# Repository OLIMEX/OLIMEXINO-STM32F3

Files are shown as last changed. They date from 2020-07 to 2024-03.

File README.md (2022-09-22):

# OLIMEXINO-STM32F3
Industrial grade -40+85C Arduino IDE programmable board with STM32F303RCT6TR Cortex-M4 CAN and USB

# OLIMEXINO-GD32F3
Industrial grade -40+85C Arduino IDE programmable board with GD32F303RCT6 Cortex-M4 CAN and USB

Product page: https://www.olimex.com/Products/Duino/STM32/OLIMEXINO-STM32F3/open-source-hardware

## Licensee
* Hardware is released under CERN Open Hardware Licence Version 2 -
Strongly Reciprocal
* Software is released under GPL3 Licensee
* Documentation is released under CC BY-SA 3.0

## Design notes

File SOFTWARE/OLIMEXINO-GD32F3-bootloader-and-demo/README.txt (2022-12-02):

The software in this archive applies only for OLIMEXINO-GD32F3

It is NOT suitable for OLIMEXINO-STM32F3

Folder "Bootloader" contains USB DFU bootloader and instructions

Folder "Blink-demo" contains blink and button demo binary and instructions

Folder "Sources" contains IAR EW sources for both the bootloader and blink

Folder "Arduno-Blink-32F3" contains Arduino project for blinking LEDs

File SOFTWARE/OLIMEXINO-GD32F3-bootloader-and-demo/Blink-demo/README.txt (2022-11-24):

Blink demo binary for OLIMEXINO-GD32F3

The demo sets the two LEDs alternatively blinking and you can pause the blinking by pressing
the SW1 button.

The demo was made with IAR EW for ARM. 

You can download the binary to your board via the microUSB connector and USB cable. 
You need to install the DFU USB drivers and your OLIMEXINO-GD32F3 needs to have USB bootloader 
software programmed (it can be found in the "Bootloader" folder).

The drivers can be downloded from GD32's web site:

https://gd32mcu.com/en/download/0?kw=GD32F3

Expand "Tool & Software" and download "GD32 Dfu Drivers". In the same place you can also find 
"GD32 All in One Programmer" so make sure to download and install that one too.

After installing the drivers start "GD32 All in One Programmer" (if you haven't already).

Load the binary. Click connect. Start Address at 0x80008000. Be careful if you use the wrong 
address you can overwrite the USB bootloader!!!

Connect the board to the micro USB cable, then set the board in USB DFU mode - this is done 
by resetting the board with button SW2 and quickly pressing SW1 (while the two LEDs are blinking 
very quickly). You have approximately 2 seconds between reset and pressing SW1 before the 
board would proceed with the user code exection. If you miss the window to press the button, 
simply reset again. When successfully set in USB DFU mode it should be listed as "GD32 Device 
in DFU mode" in your operating system.

Click download.

Refer to the picture "2-USB-gd32-allinoneprogrammer.png".

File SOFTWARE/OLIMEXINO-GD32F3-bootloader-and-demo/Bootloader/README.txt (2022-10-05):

USB bootloader binary for OLIMEXINO-GD32F3

You can download it to your board via USB-serial adapter attached 
to UEXT pins #2, #5, #6 and "GD32 All in One Programmer".

Alternatively you can use JTAG/SWD programmer using the 0.05" step
10-pin connector.

The drivers can be downloded from GD32's web site:

https://gd32mcu.com/en/download/0?kw=GD32F3

Expand "Tool & Software" you can find "GD32 All in One Programmer" 
make sure to download and install it.

Start Address at 0x80000000.

Refer to the "1-serial-gd32-allinoneprogrammer.png" picture.

If using the serial bootloader to download the USB bootloader,
remember to enter UART bootloader mode: press and hold button SW1,
press and release reset button SW2, release button SW1.

Instructions on how to use the newly downloaded USB DFU bootloder
can be found here:

https://github.com/OLIMEX/OLIMEXINO-STM32F3/blob/master/SOFTWARE/OLIMEXINO-GD32F3-bootloader-and-demo/Blink-demo/README.txt

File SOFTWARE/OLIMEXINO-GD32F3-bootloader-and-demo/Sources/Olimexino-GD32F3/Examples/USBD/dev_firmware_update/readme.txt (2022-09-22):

/*!
    \file    readme.txt
    \brief   description of the USB DFU(device firmware upgrade) demo.

    \version 2020-08-01, V3.0.0, firmware for GD32F30x
    \version 2022-06-10, V3.1.0, firmware for GD32F30x
*/

/*
    Copyright (c) 2022, GigaDevice Semiconductor Inc.

    Redistribution and use in source and binary forms, with or without modification, 
are permitted provided that the following conditions are met:

    1. Redistributions of source code must retain the above copyright notice, this 
       list of conditions and the following disclaimer.
    2. Redistributions in binary form must reproduce the above copyright notice, 
       this list of conditions and the following disclaimer in the documentation 
       and/or other materials provided with the distribution.
    3. Neither the name of the copyright holder nor the names of its contributors 
       may be used to endorse or promote products derived from this software without 
       specific prior written permission.

    THIS SOFTWARE IS PROVIDED BY THE COPYRIGHT HOLDERS AND CONTRIBUTORS "AS IS" 
AND ANY EXPRESS OR IMPLIED WARRANTIES, INCLUDING, BUT NOT LIMITED TO, THE IMPLIED 
WARRANTIES OF MERCHANTABILITY AND FITNESS FOR A PARTICULAR PURPOSE ARE DISCLAIMED. 
IN NO EVENT SHALL THE COPYRIGHT HOLDER OR CONTRIBUTORS BE LIABLE FOR ANY DIRECT, 
INDIRECT, INCIDENTAL, SPECIAL, EXEMPLARY, OR CONSEQUENTIAL DAMAGES (INCLUDING, BUT 
NOT LIMITED TO, PROCUREMENT OF SUBSTITUTE GOODS OR SERVICES; LOSS OF USE, DATA, OR 
PROFITS; OR BUSINESS INTERRUPTION) HOWEVER CAUSED AND ON ANY THEORY OF LIABILITY, 
WHETHER IN CONTRACT, STRICT LIABILITY, OR TORT (INCLUDING NEGLIGENCE OR OTHERWISE) 
ARISING IN ANY WAY OUT OF THE USE OF THIS SOFTWARE, EVEN IF ADVISED OF THE POSSIBILITY 
OF SUCH DAMAGE.
*/

  This demo is based on the GD32F303E-EVAL board,it presents the implementation 
of a device firmware upgrade (DFU) capability in the GD32 USB device.

  It follows the DFU class specification defined by the USB Implementers Forum for 
reprogramming an application through USB-FS-Device.

  The DFU principle is particularly well suited to USB-FS-Device applications that 
need to be reprogrammed in the field.

  The supported memorys of this example are the internal flash memory, the external 
nand flash memory and the external nor flash memory.

  To test the demo, the internal flash is used as an example:

  Step 1: User need a configuration hex image or bin image. The hex image and the bin image 
should set application address at APP_LOADED_ADDR in the internal flash memory. User can refer to
"../Test_Images" folder and use the hex images and bin images in it.

  Step 2: User need install the corresponding GD DFU Driver with your PC operation system. 

  Step 3: Once the configuration *.hex image is generated, it can be downloaded into the 
internal flash memory or the external falsh memory using the GD tool "GD32 MCU DFUEx Tool
" available for download from http://www.gd32mcu.com/cn/download.

  The GD tool "GD32AllInOneProgrammer" can operate the option Byte in the internal flash.

  Step 4: After each device reset, hold down the TAMPER key on the GD32207i-EVAL board into app 
routine in the internal flash.

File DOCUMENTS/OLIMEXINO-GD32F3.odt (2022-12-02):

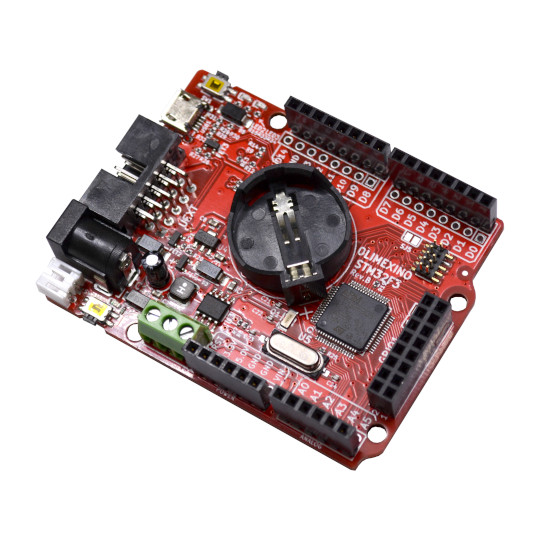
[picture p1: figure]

OLIMEXINO-GD32F3

User Manual

Document revision 1.0 December 2022

www.olimex.com

# What is OLIMEXINO-GD32F3

It is a version of OLIMEXINO-STM32F3 but with GigaDevice’s GD32F3 chip. The STM32F3 and GD32F3 chips are very similar and the variant was designed due to unavailability of STM32 chips.

## Differences between OLIMEXINO-STM32F3 and OLIMEXINO-GD32F3

The main chip is different which leads to a few major differences between the two boards. The major differences affecting the user are:

1) GD32F303 chip has no built-in USB bootloader, only serial one (USART0 or USART1 can be used to re-program the board without programmer). In order to program the board you might need either USB-serial adapter cable SWD programmer (with proper cabling to fit the 10pin, 0.05” step on-board connector). You can find

2) Memory maps are different. If you compare the memory organization and maps in the datasheets of both chips you would notice the memory organization is different. This effectively makes almost any binary made for the STM32F3 version incompatible with the GD32F3 version. Also renders some of the tools unusable. For example, for Arduino you would have to use special core for GD32 chips, instead of the official STM32 duino project.

3) The built-in serial uses the I2C pins at the UEXT (e.g. I2C and UART are swapped in the GD32F3 board – the UEXT pins 3 and 4 are I2C and pins 5 and 6 are UART).

OLIMEXINO-GD32F3 is an industrial grade -40+85C operating temperature, Open Source Hardware board with GD32F303RCT6 main chip. The chip has 256 KB of flash memory and 48 KB of RAM. The board works with powered off a Li-Po battery without an external supply, and switching between USB to external to Li-Po battery power supply is seamless and automatic. If USB is connected the board gets powered by the USB, if external power is applied to the power jack – it has priority over the USB and battery and the board will be powered by the external power supply, if both external power supply and USB power supply are missing but a battery is connected the board would automatically get powered by the LiPo battery. In GD32F3 series of microcontrollers the CAN and the USB can work at the same time.

OLIMEXINO-GD32F3 has following features:

- GD32F303RCT6 256KB flash, 40KB RAM
- Industrial grade (-40+85)°C operating temperature
- Micro USB connector for powering and programming
- Power jack (5.5mm x 2mm) for external power supply (4.2-40)V DC
- Li-Po battery charger and connector
- Micro SD card
- RTC 32.768kHz with CR2032 battery connector
- Bootloader button
- Reset Button
- CAN driver and connector
- UEXT connector
- Arduino connectors
- Extra 16 pin GPIO connector
- 10-pin JTAG connector for programming and debugging

Product page:

https://www.olimex.com/Products/Duino/STM32/OLIMEXINO-GD32F3/open-source-hardware

# Hardware schematic, revision C1

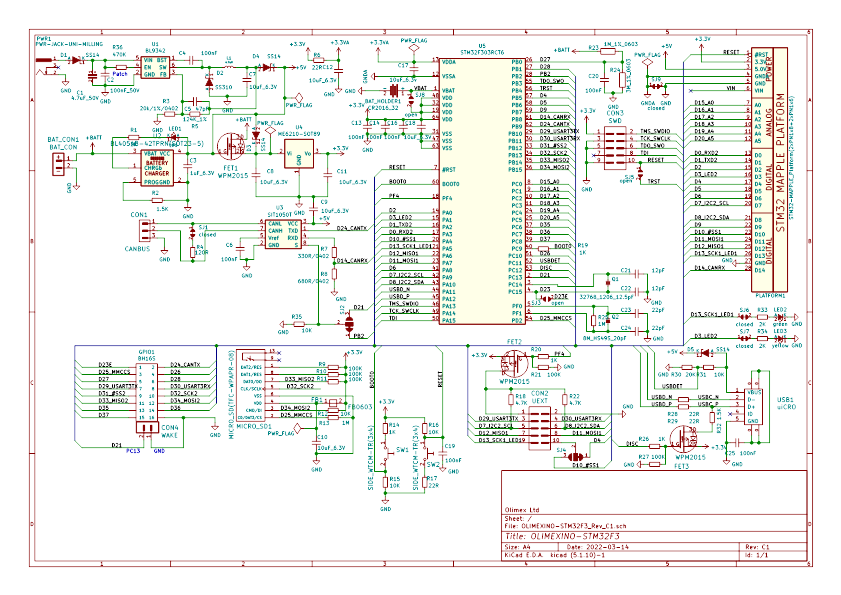
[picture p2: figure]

# Programming considerations

By default there are two ways to program the OLIMEXINO-GD32F3 – either via USB-serial cable attached to the UART pins at the UEXT; or via external programmer attached to the 10-pin SWD connector.

Alternatively, you can program the board with DFU USB bootloader, it will be possible to program it via the micro USB port too (but there is no DFU USB bootloader programmed by default).

No matter the method chosen you can use a number of software tools tool provided by GigaDevices or the Arduino community.

# Using stand-alone programmer software

The compatible software tool can be downloaded from GigaDevice’s web-site. It is called “GD32 All-In-One Programmer”. It allows to program the board via USB-serial cable, using USB DFU bootloader, or a special programmer tool “GD USB adapter”. We would cover the first two ways.

But first go to:

https://gd32mcu.com/en/download/0?kw=GD32F3

Expand the list of “Tools & Software” and download “GD32 All-In-One Programmer” from the button.

After the download is completed, extra the archive.

Inside you will find “GD32AllInOneProgrammer.exe” – run it to start the application.

## Programming via serial bootloader

You can program the board via its internal bootloader via external USB-serial adapter (with 3.3V levels). I use Olimex BB-CH340T and three wires attached to UEXT pins #2(GND), #5(TX), #6(RX). I power the board from the power jack (but you can power it from a micro USB cable too).

Once the hardware connections are established, remember to set the OLIMEXINO-GD32F3 board in bootloader mode. This is done by:

- press and hold button SW1

- press and release button SW2

- release button SW1

In “GD32 All In One Programmer” software set:

- “Interface” to “COM”;

- “BootLoader” to “UART”;

- “Port Name” to the COM port assigned to the USB-serial cable

- “Part Number” to GD32F303RCT.

- “Start Address” at “0x8000000”

- Mark “Full Chip erase”

There is a reference picture on the next page that shows how the settings look here. COM10 is where my USB-serial adapter BB-CH340T is listed by Windows.

Once done click the button “Connect”. If it doesn’t connect then double-check all previous steps, you probably swapped RX and TX wires or didn’t enter bootloader mode with the buttons.

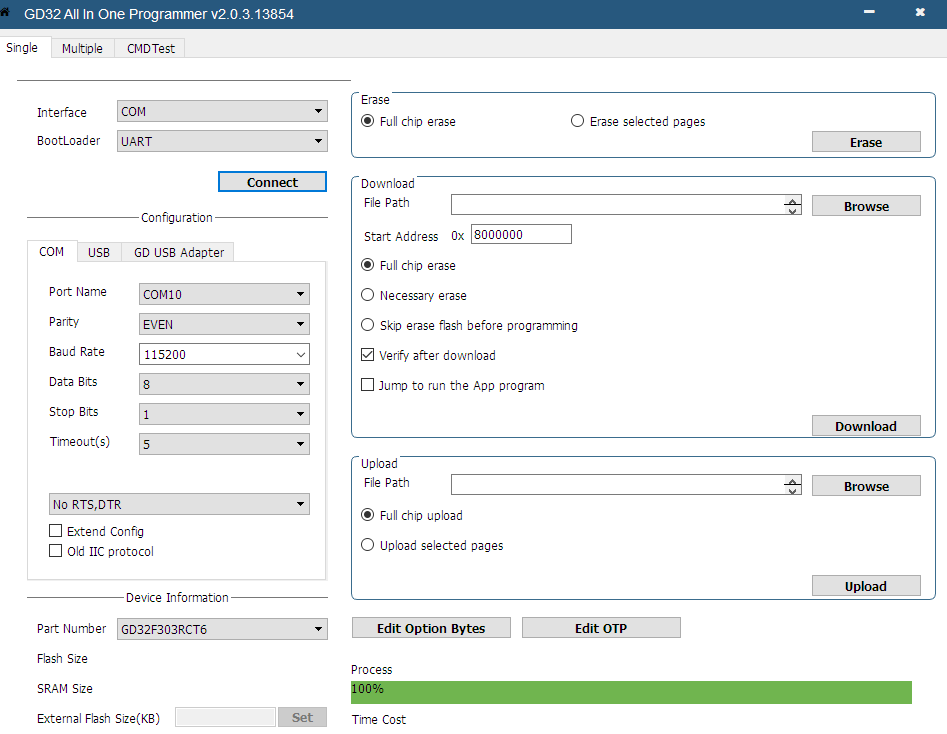
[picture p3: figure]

After the connection is successful you can download a binary from the “Download” section and navigating with “Browse” button.

## Programming via USB

OLIMEXINO-GD32F3 boards come without USB bootloader. If you wish to program the board via USB you need to first download USB bootloader via serial bootloader or via JTAG. You can find such here:

https://github.com/OLIMEX/OLIMEXINO-STM32F3/tree/master/SOFTWARE/OLIMEXINO-GD32F3-bootloader-and-demo/Bootloader

Programming via the USB requires to first install the USB drivers. The drivers can be downloaded from GD32's web site: https://gd32mcu.com/en/download/0?kw=GD32F3

Expand "Tool & Software" you can find "GD32 All in One Programmer" make sure to download and install it.

After installing the drivers start "GD32 All in One Programmer" (if you haven't already).

Load the binary. Click connect. Start Address at 0x80008000. Be careful if you use the wrong address you can overwrite the USB bootloader!!!

Connect the board to the micro USB cable, then set the board in USB DFU mode – this is done by resetting the board with button SW2 and quickly pressing SW1 (while the two LEDs are blinking very quickly). You have approximately 2 seconds between reset and pressing SW1 before the board would proceed with the user code execution. If you miss the window to press the button, simply reset again. When successfully set in USB DFU mode it should be listed as "GD32 Device in DFU mode" in your operating system.

Click download.

Refer to the picture on the next page on how GD32 All in One Programmer window looks like when programming via the USB.

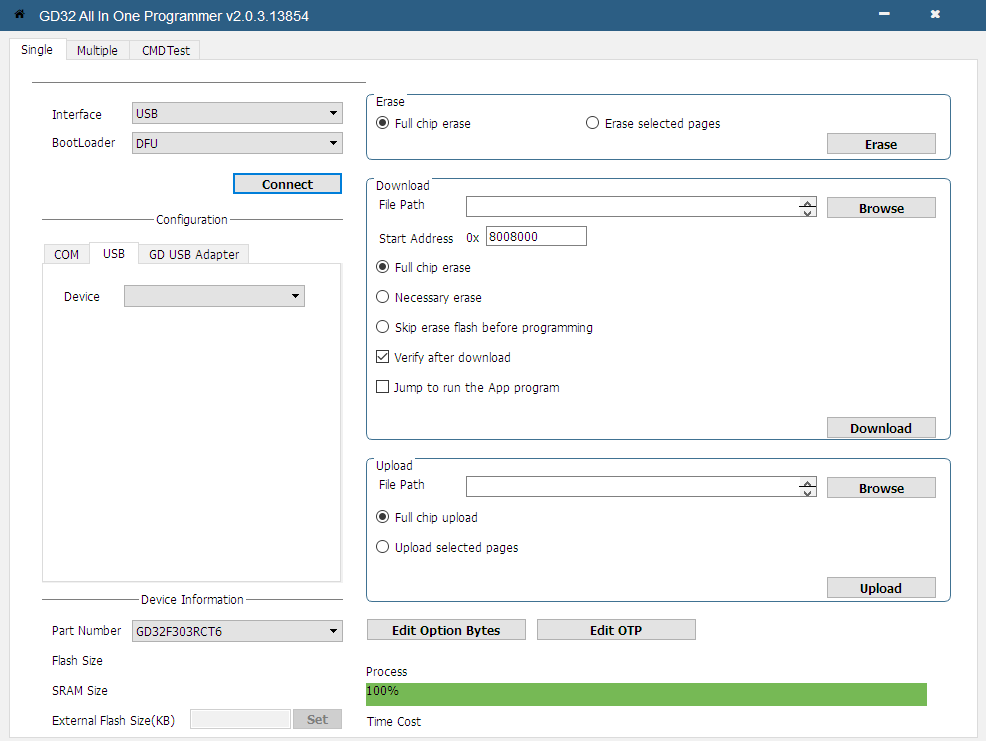
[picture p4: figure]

# Using Arduino IDE

Notice that OLIMEXINO-GD32 does not work with STM32duino package but there is a community effort project called “ArduinoCore-GD32” that can be found here:

https://github.com/CommunityGD32Cores/ArduinoCore-GD32

1. How to add “ArduinoCore-GD32” to Arduino IDE? In Arduino IDE navigate to Files→ Preferences and in “Additional Boards Manager URLs” field add the following link:

https://raw.githubusercontent.com/CommunityGD32Cores/GD32Core-New/main/package_gd32_index.json

It should looks similar to this:

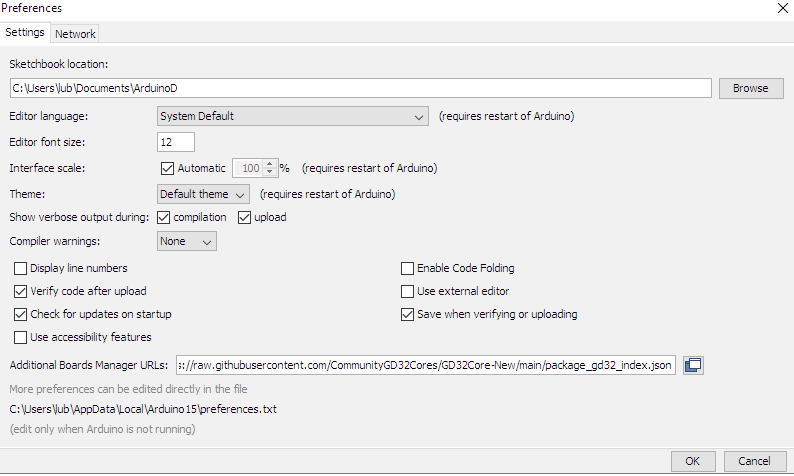
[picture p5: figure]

2. Then navigate to Tools→ Boards → Board Manager

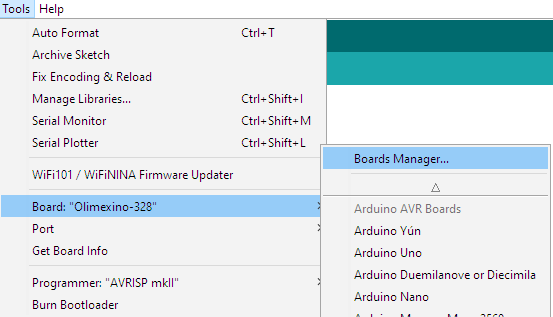
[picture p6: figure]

3. Type “gd32” to filter out the available packages then install the latest one made by “Some random folks”. Wait until installations completes. It should look similar to this:

4. Restart Arduino IDE.

5. Now select the board. Under “Board” select “GD32F30x Generic series”. It looks like this:

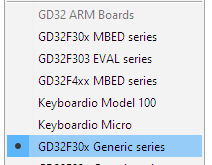
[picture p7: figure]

Now you have several paths ahead depending on how you plan to program the board. You can program it via serial bootloader, via USB DFU (not available by default), via external programmer tool with SWD interface (requires GDlink, ST-link, or J-Link programmer tool). All options are visible here:

5.1 (option serial bootloader) Under upload method remember to select “Serial”, which is serial method that requires Serial-USB adapter attached to the UEXT pins #2(GND), #5(TX), #6(RX). Power the board from the power jack (but you can power it from a micro USB cable too).

Once the hardware connections are established, remember to set the OLIMEXINO-GD32F3 board in serial bootloader mode. This is done by:

- press and hold button SW1

- press and release button SW2 (SW2 is reset button)

- release button SW1

You need to enter bootloader mode every time before clicking the Arduino IDE button “Upload”, else the upload would fail.

5.2 (option USB DFU) This only works if you have downloaded USB DFU to the board. Under upload method remember to select “dfu-util (DFU – STMDuino bootloader), which is the micro USB method.

How to download USB DFU to the board? Refer to chapter “Programming via USB” above in this document, it explains how to download the USB DFU. Now connect the board to the micro USB cable, then set the board in USB DFU mode – this is done by resetting the board with button SW2 and quickly pressing SW1 (while the two LEDs are blinking very quickly). You have approximately 2 seconds between reset and pressing SW1 before the board would proceed with the user code execution. If you miss the window to press the button, simply reset again. When successfully set in USB DFU mode it should be listed as "GD32 Device in DFU mode" in your operating system.

5.3 (option JTAG) Connect one of the three supported JTAG tools to the on-board SWD connector. It is a standard 0.05 inch step 10-pin connector. If your tool doesn’t fit and you don’t have an adapter, then consider this adapter ARM-JTAG-20-10:

https://www.olimex.com/Products/ARM/JTAG/ARM-JTAG-20-10/

Then select Tools → Upload Method → GDLink(SWD) or STLink(SWD) or Jlink(SWD), depending on the tool you have.

6. Once the chosen method for downloading code is set and selected, we have to download some code. Load a blinking LED example corresponding to the board’s hardware. Try this blinking LED code:

void setup() {

// initialize PA5(LED1) and PA1(LED2) as outputs.

pinMode(PA5, OUTPUT);

pinMode(PA1, OUTPUT);

}

// the loop function runs over and over again forever

void loop() {

digitalWrite(PA5, HIGH); // turn LED1 on (HIGH is the voltage level)

digitalWrite(PA1, LOW); // turn LED2 off by making the voltage LOW

delay(1000); // wait for a second

digitalWrite(PA5, LOW); // turn LED1 off by making the voltage LOW

digitalWrite(PA1, HIGH); // turn LED2 on (HIGH is the voltage level)

delay(1000); // wait for a second

}

Click the upload button, and wait until success. There are more example from File → Examples. They can be found under “Examples for GD32F30x Generic series”. Notice that some macros might not correspond to OLIMEXINO-GD32F3 and you might need to declare pins directly or edit variant.h in the package. It is usually located in:

C:\Users\[yourusername]\AppData\Local\Arduino15\packages\GD32Community\hardware\gd32\0.0.1\variants\GD32F303CC_GENERIC

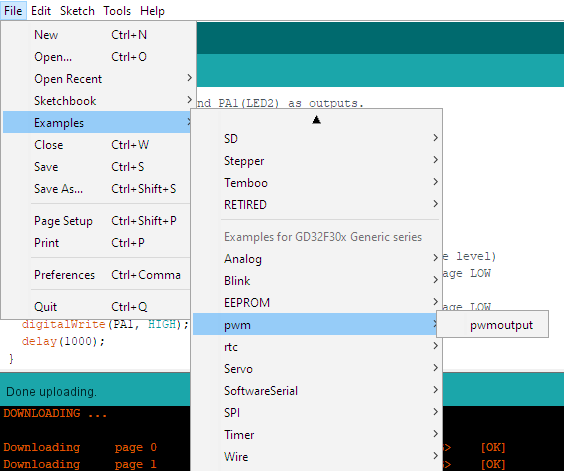
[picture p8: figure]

# Programming via JTAG

Allows for general-purpose programming of the board. This way you can use ARM development environments like IAR EW for ARM (that we have used successfully). The JTAG also can be used with certain packages in Arduino IDE and PlatformIO that have support for both GD32 chips and JTAG. Notice that “ArduinoCore-GD32” package for Arduino has support only for three JTAGs -

Notice that the OLIMEXINO-GD32F3 board has only SWD (Serial Wire Debug) interface exposed on the connector (it is not a full JTAG). Make sure your tool has SWD support. The on-board SWD connector is a standard 0.05 inch step 10-pin connector. If your tool doesn’t fit and you don’t have an adapter, then consider this adapter ARM-JTAG-20-10:

https://www.olimex.com/Products/ARM/JTAG/ARM-JTAG-20-10/

# Software examples and libraries

Notice that demos for OLIMEXINO-GD32F3 and OLIMEXINO-STM32F3 are incompatible due to memory map differences.

There is a USB DFU firmware made with IAR EW.

There is a blink demo made with IAR EW.

There is a blink demo made with Arudino IDE.

All can be found here: https://github.com/OLIMEX/OLIMEXINO-STM32F3/tree/master/SOFTWARE/OLIMEXINO-GD32F3-bootloader-and-demo

# Revision history

Revision 1.0 December 2022

- Initial release

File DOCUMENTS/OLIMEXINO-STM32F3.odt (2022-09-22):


OLIMEXINO-STM32F3

User Manual

Document revision 2.0 September 2022

www.olimex.com

# What is OLIMEXINO-STM32F3

OLIMEXINO-STM32F3 is an industrial grade -40+85C operating temperature, Open Source Hardware board with STM32F303RCT6 main chip. The chip has 256 KB of flash memory and 48 KB of RAM. The board works with powered off a Li-Po battery without an external supply, and switching between USB to external to Li-Po battery power supply is seamless and automatic. If USB is connected the board gets powered by the USB, if external power is applied to the power jack – it has priority over the USB and battery and the board will be powered by the external power supply, if both external power supply and USB power supply are missing but a battery is connected the board would automatically get powered by the LiPo battery.

In STM32F3 series of microcontrollers the CAN and the USB can work at the same time.

Notice that this guide is not suitable for OLIMEXINO-GD32F3!

OLIMEXINO-STM32F3 has following features:

- STM32F303RCT6 256KB flash, 40KB RAM
- Industrial grade (-40+85)°C operating temperature
- Micro USB connector for powering and programming
- Power jack (5.5mm x 2mm) for external power supply (4.2-40)V DC
- Li-Po battery charger and connector
- Micro SD card
- RTC 32.768kHz with CR2032 battery connector
- Bootloader button
- Reset Button
- CAN driver and connector
- UEXT connector
- Arduino connectors
- Extra 16 pin GPIO connector
- 10-pin JTAG connector for programming and debugging

Product page:

https://www.olimex.com/Products/Duino/STM32/OLIMEXINO-STM32F3/open-source-hardware

# Hardware schematic, revision C1


# Programming considerations

OLIMEXINO-STM32F3 can be programmed via a number of ways. It can be programmed via JTAG or SWD tool using its 10-pin JTAG connector; it can be programmed via the built-in USB or serial bootloader. A lot of software tools can be used. For simple programming and re-programming tasks maybe consider “STM32CubeProgrammer” stand-alone programmer software. For development work again a lot of software tools can be used depending on the goals and proficiency of the user. We would provide information about how you can program the board with Arduino IDE:

# Arduino IDE installation

1. In Arduino IDE navigate to Files→ Preferences and in “Additional Boards Manager URLs” field add the following link:

https://github.com/stm32duino/BoardManagerFiles/raw/main/package_stmicroelectronics_index.json

as shown below:

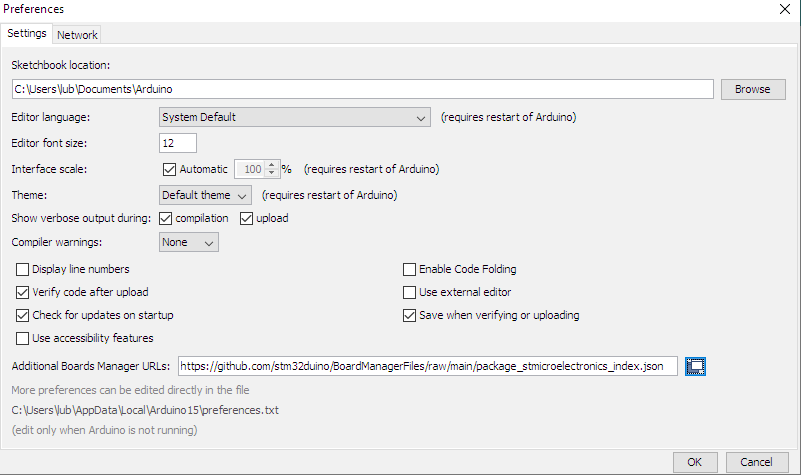
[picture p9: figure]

2. Then navigate to Tools→ Boards → Board Manager


3. Type “stm32” to filter out the available packages then install the latest one made by STMicroelectronics. Wait until installations completes. It should look similar to this:

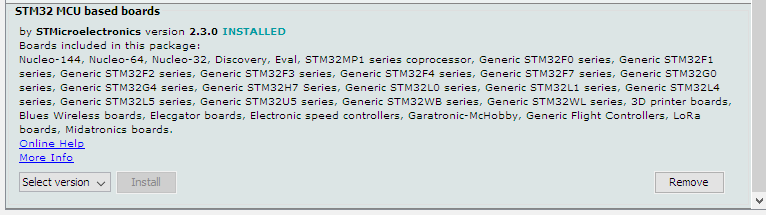
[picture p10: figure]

4. We want to upload the demo via USB DFU. And if you wish to upload via SWD, Serial, or DFU you need to install STM32 Cube Programmer (https://www.st.com/en/development-tools/stm32cubeprog.html) – make sure to download and install it.

5. Restart Arduino IDE.

6. Now select the board. Under “Board” select “Generic STM32F3 series” and under “Board part number:” go for “OLIMEXINO-STM32F3”. Under upload method remember to select DFU, which is the microUSB method (alternatively you can also serial method but that requires Serial-USB adapter attached to the GND, RX, TX pins at the UEXT connector). Follow the image below:

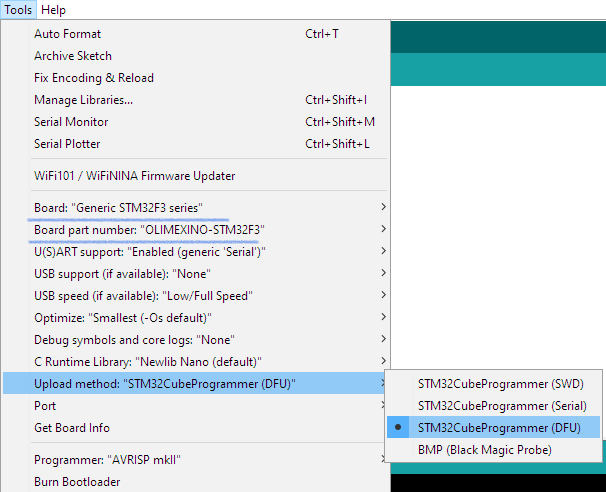
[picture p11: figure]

7. Put the board in USB DFU mode – this is done by button manipulation – press and hold down button SW1 then press and release button SW2, then release button SW1. The board should now be recognized as “STM32 bootloader”.

8. Load one of the examples from File → Examples. Maybe Examples → 01.Basics → Blink. Click the upload button and wait until success.

If you encounter issues with the installation make sure to also check the official installation instructions:

https://github.com/stm32duino/wiki/wiki/Getting-Started

# Software examples and libraries

You can find our work here:

https://github.com/OLIMEX/OLIMEXINO-STM32F3/tree/master/SOFTWARE

In GitHub software folder there are examples on how to use the GPIOs (LEDs and button), I2C, SPI (we provide new library for this as otherwise you couldn’t use the micro SD card as original Arduino library support just one SPI), CAN, UART, SD-card, LCD3310.

There is also an example with MOD-LCD2.8RTP.

# Document revision history

Revision 2.0 September 2022

- Updated installation instructions

- Updated schematic to latest one

- Minor spelling and design improvements

Revision 1.0 July 2020

- Initial release of the document

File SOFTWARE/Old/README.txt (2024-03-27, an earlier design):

These examples worked with STM32duino package 1.9.0 patched with the files inside "Package files" directory.
Read the "HowTo.txt" for further instruction on how to do it.

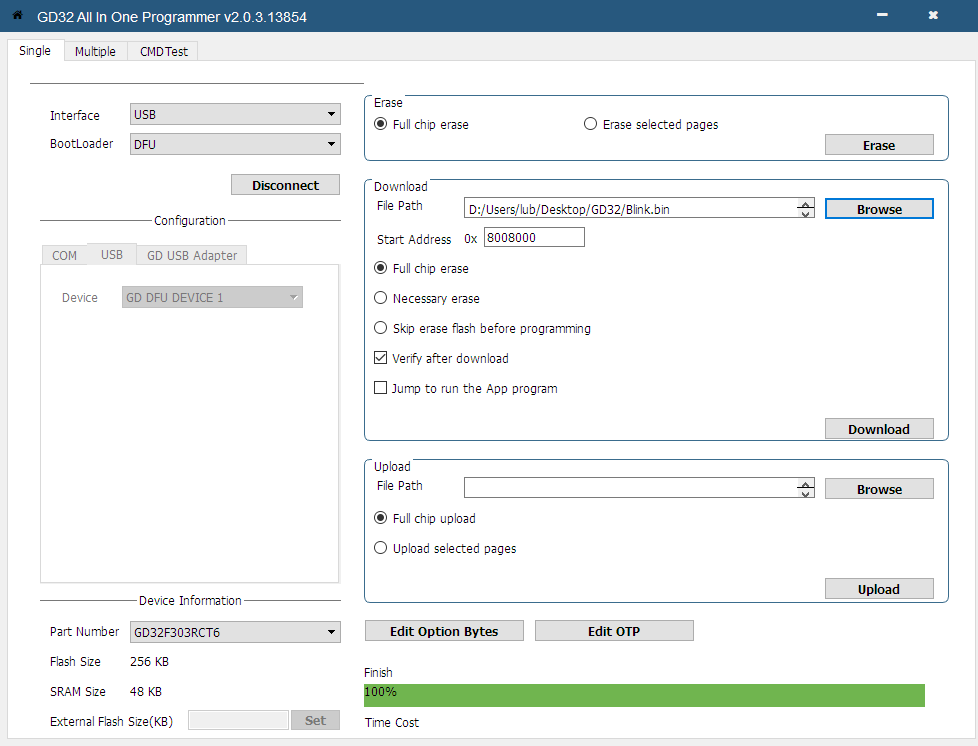
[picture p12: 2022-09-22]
SOFTWARE/OLIMEXINO-GD32F3-bootloader-and-demo/Blink-demo/2-USB-gd32-allinoneprogrammer.png

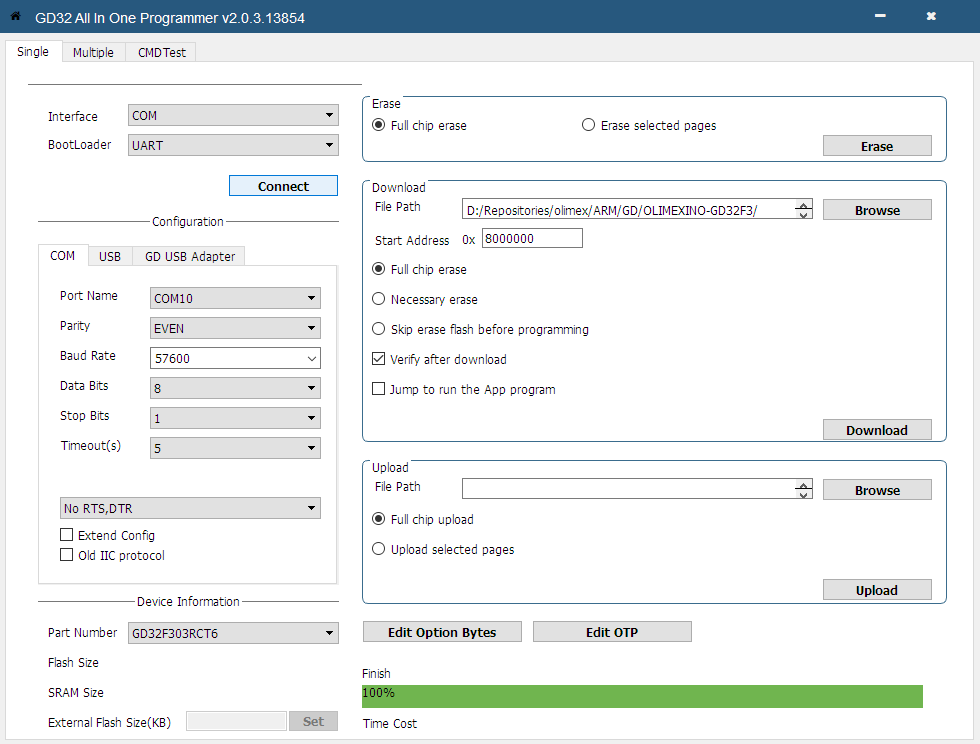
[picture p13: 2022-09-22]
SOFTWARE/OLIMEXINO-GD32F3-bootloader-and-demo/Bootloader/1-serial-gd32-allinoneprogrammer.png

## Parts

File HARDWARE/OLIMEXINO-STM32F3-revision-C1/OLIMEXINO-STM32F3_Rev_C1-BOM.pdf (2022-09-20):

# OLIMEXINO-STM32F3_Rev_C1-BOM 03/14/2022

Designation | Qua ntity | Designator | Package
SMD ДИОД 1N5819 (SS14) SMA | 4 | D5,D4,D3,D1 | SMA-KA
SMD RES 0402 124 K OHM 1% | 1 | R5 | R_0402_5MIL_DWS
SMD CAP 0603 1 UF 10V X5R | 1 | C3 | C_0603_5MIL_DWS
SMD RES 0402 20 K 1% | 1 | R3 | R_0402_5MIL_DWS
FB0603 | 1 | FB1 | L_0603_5MIL_DWS
MALE-PAV16X-2x05-LOW | 1 | CON3 | SWD /маха се 7ми крак/
n.i. | 1 | CON4 | HN1x2
SMD ИНДУКТИВНОСТ CD43 4.7 UH (NRS4018T4R7MDGJ) | 1 | L1 | CD43
SMD ИС BL4054B-42TPRN | 1 | U2 | SOT-23-5
SMD ИС BL9342 | 1 | U1 | SOT23-6
SMD ИС ME6210A33PG | 1 | U4 | SOT89
SMD ИС SIT1050T | 1 | U3 | SO-8
SMD КЛЮЧ БУТОН TSW34-W16PR-220-LF / SIDE | 2 | SW2,SW1 | TSW34-W16PR-220
SMD КОНД 0402 100 NF 10% 10VDC | 8 | C25,C20,C19,C16,C14,C13,C6,C 4 | C_0402_5MIL_DWS
SMD КОНД 0402 12 PF NP0 5% | 2 | C22,C21 | C_0402_5MIL_DWS
SMD КОНД 0402 22 PF NP0 5% | 2 | C24,C23 | C_0402_5MIL_DWS
SMD КОНД 0402 47 PF C0G 50VDC 5% | 1 | C5 | C_0402_5MIL_DWS
SMD КОНД 0603 10 UF 6.3V | 8 | C18,C17,C12,C11,C10,C9,C8,C7 | C_0603_5MIL_DWS
SMD КОНД 0805 100 NF X7R 50VDC 10% | 1 | C2 | C_0805_5MIL_DWS
SMD RES 0402 330 OHM 5% | 1 | R7 | R_0402_5MIL_DWS
SMD RES 0402 680 OHM 5% | 1 | R8 | R_0402_5MIL_DWS
SMD РЕЗ 0402 1 K 5% | 4 | R26,R20,R19,R14 | R_0402_5MIL_DWS
SMD РЕЗ 0402 1 M 5% | 2 | R25,R13 | R_0402_5MIL_DWS
SMD РЕЗ 0402 1.5 K 5% | 1 | R32 | R_0402_5MIL_DWS
SMD РЕЗ 0402 1.5 K 5% | 1 | R2 | R_0402_5MIL_DWS
SMD РЕЗ 0402 10 K 5% | 5 | R35,R31,R16,R15,R12 | R_0402_5MIL_DWS
SMD РЕЗ 0402 100 K 5% | 5 | R27,R21,R11,R10,R9 | R_0402_5MIL_DWS
SMD РЕЗ 0402 120 OHM 5% | 1 | R4 | R_0402_5MIL_DWS
SMD РЕЗ 0402 2 K 5% | 3 | R34,R33,R1 | R_0402_5MIL_DWS
SMD РЕЗ 0402 20 K 5% | 1 | R30 | R_0402_5MIL_DWS
SMD РЕЗ 0402 22 OHM 5% | 4 | R29,R28,R17,R6 | R_0402_5MIL_DWS
SMD РЕЗ 0402 4.7 K 5% | 2 | R22,R18 | R_0402_5MIL_DWS
SMD РЕЗ 0603 1 M 1% | 1 | R23 | R_0603_5MIL_DWS
SMD РЕЗ 0603 3 M 1% | 1 | R24 | R_0603_5MIL_DWS
SMD РЕЗ. КВАРЦ 32.768 kHz SMD1206 12.5pf | 1 | Q1 | L_1206_5MIL_DWS
SMD РЕЗОНАТОР КВАРЦ HU49S 8 MHZ 20PF 20PPM | 1 | Q2 | Q_49U3HMS
SMD СВЕТОДИОД 0603 ЖЪЛТ 150 mCd | 1 | LED3 | LED_0603_KA
SMD СВЕТОДИОД 0603 ЗЕЛЕН 300 mCd | 1 | LED2 | LED_0603_KA

# OLIMEXINO-STM32F3_Rev_C1-BOM 03/14/2022

SMD СВЕТОДИОД 0603 ЧЕРВЕН 300 mCd | 1 | LED1 | LED_0603_KA
SMD СЪЕДИНИТЕЛ MISB-SWMM-5B-LF | 1 | USB1 | USB-MICRO_MISB-SWMM-5B_LF
SMD СЪЕДИНИТЕЛ TFC-WPAPR-08 (микро SD-карта) | 1 | MICRO_SD1 | MICRO_SD(TFC-WXCP11-08-LF)
SMD ТРАНЗИСТОР WPM2015-3/TR | 3 | FET3,FET2,FET1 | SOT23
STM32F303RCT6 | 1 | U5 | LQFP64_Pitch-0.5mm_12.00x12.00x1.6 0mm
КЛЕМА TB3-3.5ММ (HD-351 3P) | 1 | CON1 | TB3-3.5mm
КОНДЕНЗАТОР 4.7 uF 50 V | 1 | C1 | CPOL-RM2mm_5x9mm_PTH
СЪЕДИНИТЕЛ BH-CR2032P 3V | 1 | BAT_HOLDER1 | CR2032-PTH-PLASTIC
СЪЕДИНИТЕЛ BH10R (B-R-10-LF) 2x5 ЪГЪЛ | 1 | CON2 | UEXT_BH10R LIPO_BAT-CON2D-
СЪЕДИНИТЕЛ DW02R | 1 | BAT_CON1 | W02R
СЪЕДИНИТЕЛ F-D-2X08-LF | 1 | GPIO1 | BH16S
СЪЕДИНИТЕЛ FE-D13A-1X06-LF(H=11.04mm) | 2 | PLATFORM1 | ARDUINO-STM32-PLATFORM
СЪЕДИНИТЕЛ FE-D13A-1X08-LF(H=11.04mm) | 2 | PLATFORM1
СЪЕДИНИТЕЛ YDJ-1134 PWRJ-2mm (DCJ-R-20-LF) | 1 | PWR1 | PWR_JACK_UNI_MILLI NG
SMD ДИОД SS310 SMA | 1 | D2 | SMA-KA
SMD РЕЗ 0402 470 K 5% | 1 | Rpatch | R_0402_5MIL_DWS

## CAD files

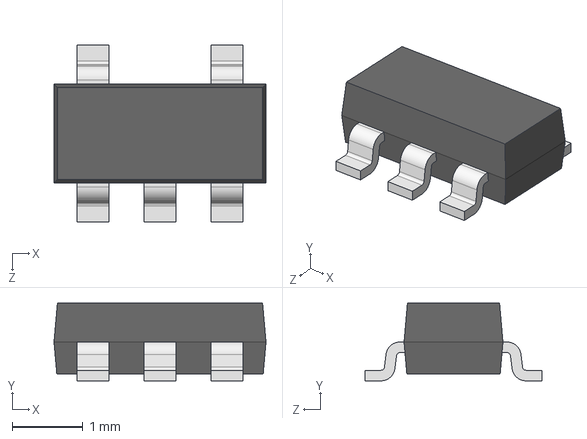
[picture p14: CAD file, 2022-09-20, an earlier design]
HARDWARE/OLIMEXINO-STM32F3-revision-B/3d/SOT-23-5.step
3.00 x 1.10 x 2.50 mm

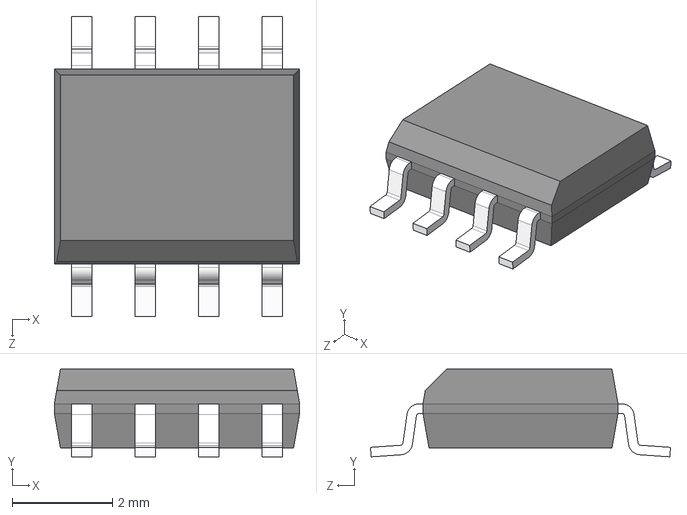
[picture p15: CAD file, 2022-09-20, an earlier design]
HARDWARE/OLIMEXINO-STM32F3-revision-B/3d/SO-8_150mil---SN65HVDA1050AQDRQ1.STEP
4.90 x 1.75 x 5.99 mm

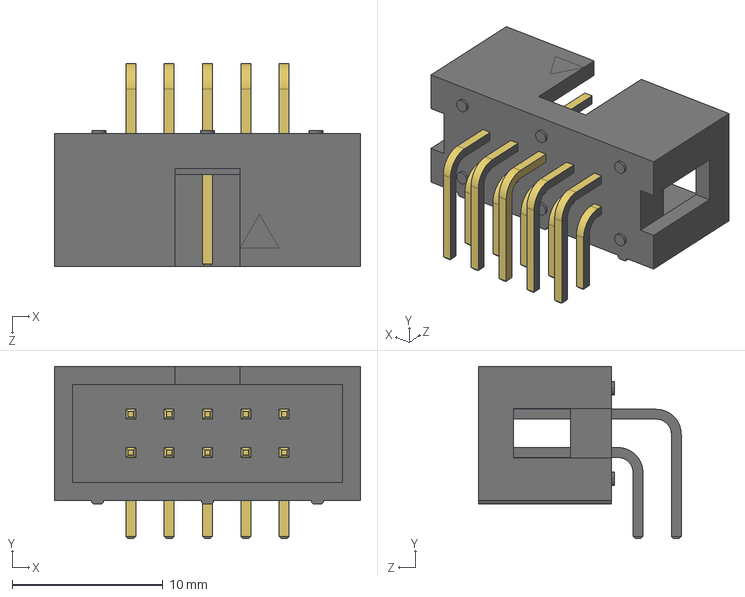
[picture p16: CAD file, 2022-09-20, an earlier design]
HARDWARE/OLIMEXINO-STM32F3-revision-B/3d/Header_right_angle_10way(2x5).step
20.3 x 11.4 x 13.4 mm

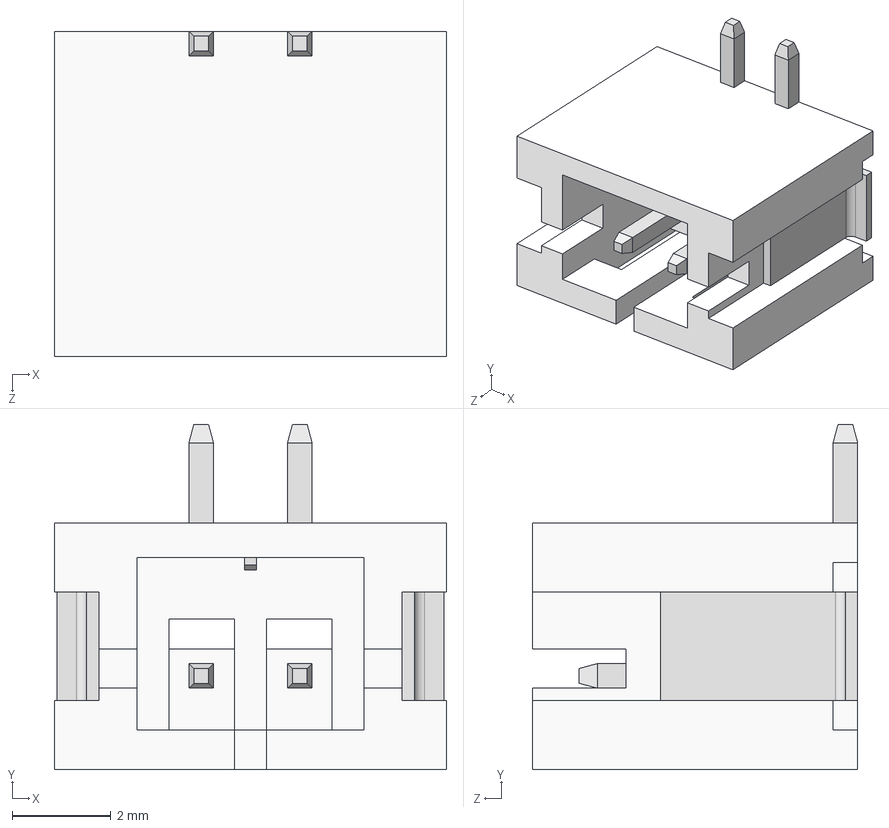
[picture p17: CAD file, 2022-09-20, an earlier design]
HARDWARE/OLIMEXINO-STM32F3-revision-B/3d/JST_B2B-PH-SM4-TB(DW02R).step
7.95 x 7.00 x 6.60 mm

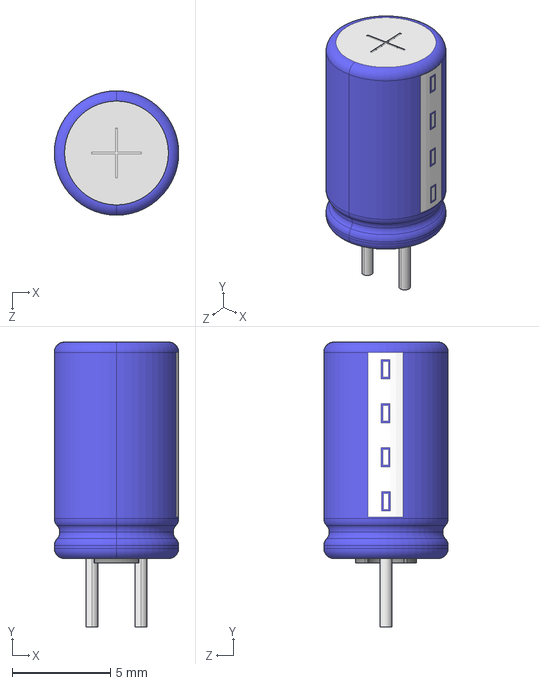
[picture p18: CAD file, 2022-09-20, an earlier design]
HARDWARE/OLIMEXINO-STM32F3-revision-B/3d/Cap_PTH_6_3x11x2_5mm.step
6.35 x 14.5 x 6.35 mm

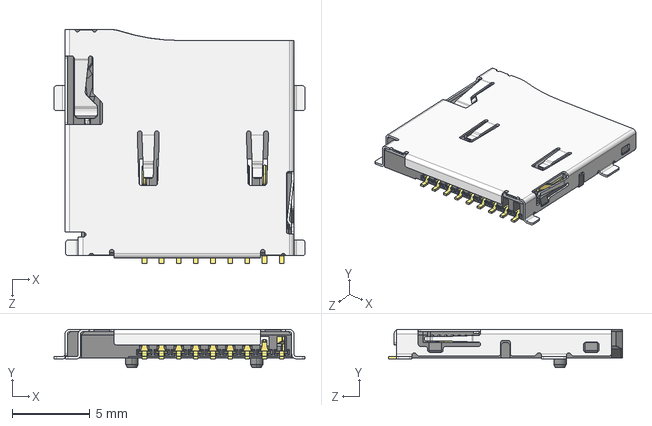
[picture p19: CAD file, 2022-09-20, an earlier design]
HARDWARE/OLIMEXINO-STM32F3-revision-B/3d/TFC-WPAPR-08---112J-TXAR-R_C_1-1.STEP
16.1 x 2.45 x 15.0 mm

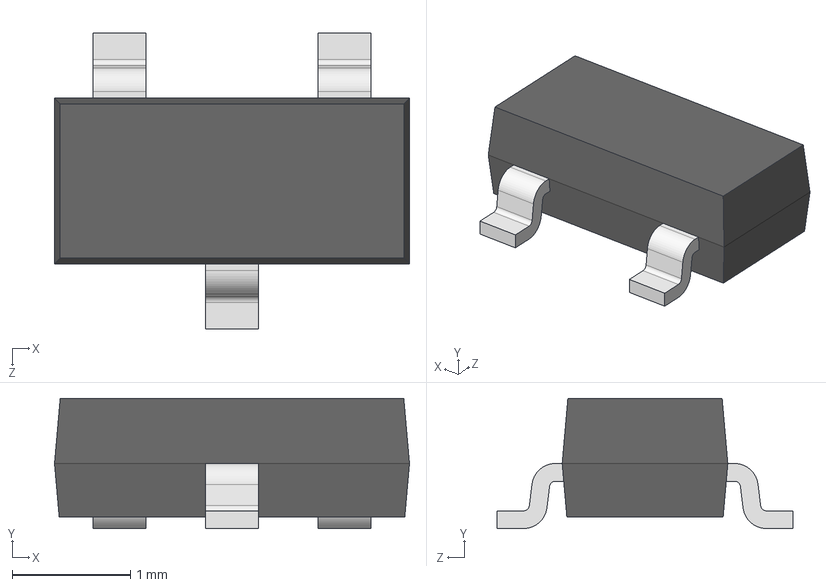
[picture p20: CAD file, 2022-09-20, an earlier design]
HARDWARE/OLIMEXINO-STM32F3-revision-B/3d/SOT-23.step
3.00 x 1.10 x 2.50 mm

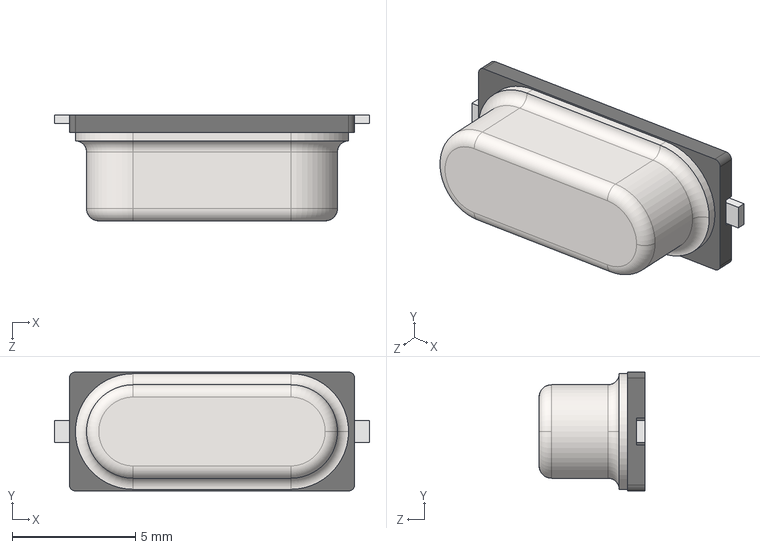
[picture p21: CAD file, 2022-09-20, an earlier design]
HARDWARE/OLIMEXINO-STM32F3-revision-B/3d/User_Library-Crystal_HC49_US-SM.step
12.8 x 4.83 x 4.30 mm

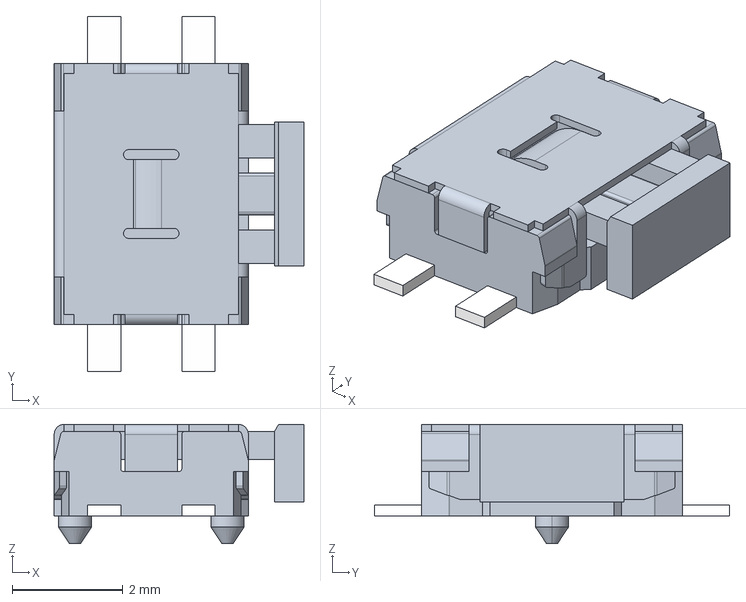
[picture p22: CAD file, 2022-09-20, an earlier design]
HARDWARE/OLIMEXINO-STM32F3-revision-B/3d/tactile_sidesw.stp
4.50 x 6.40 x 2.15 mm

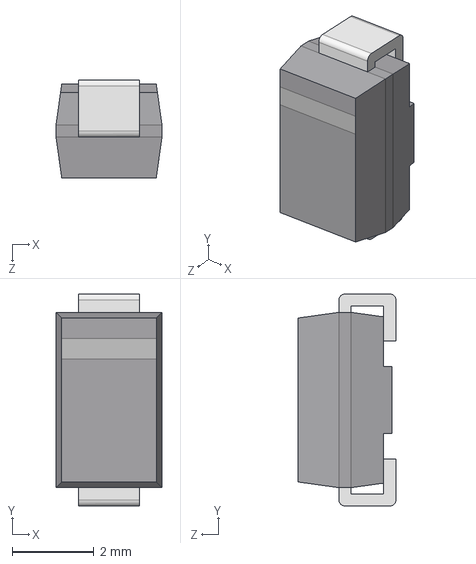
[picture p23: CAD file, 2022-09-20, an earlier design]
HARDWARE/OLIMEXINO-STM32F3-revision-B/3d/DO-214AC_SMA.step
2.60 x 5.20 x 2.40 mm

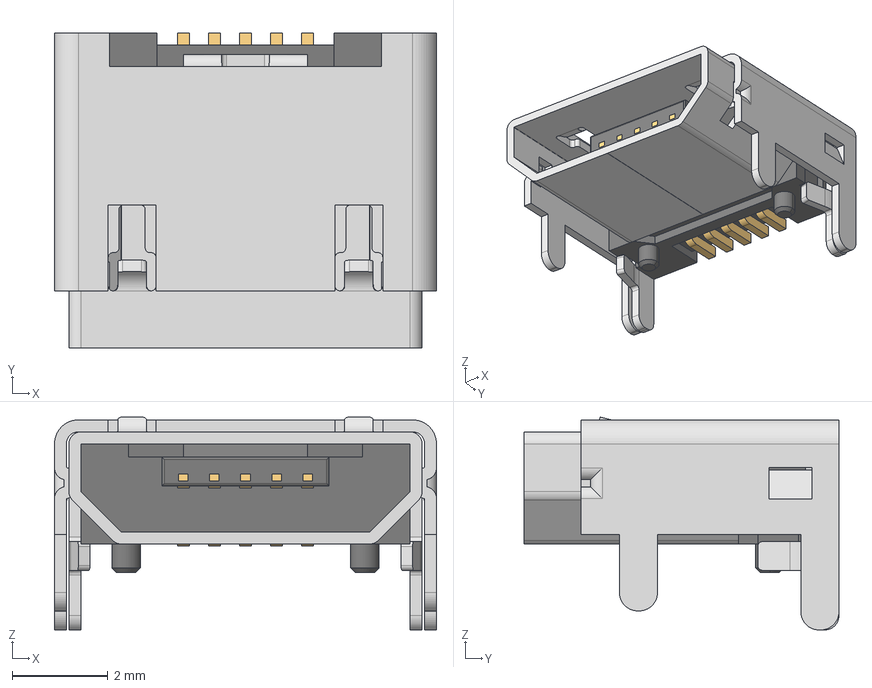
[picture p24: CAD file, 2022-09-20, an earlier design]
HARDWARE/OLIMEXINO-STM32F3-revision-B/3d/usb_micro_4p.stp
8.00 x 6.60 x 4.46 mm

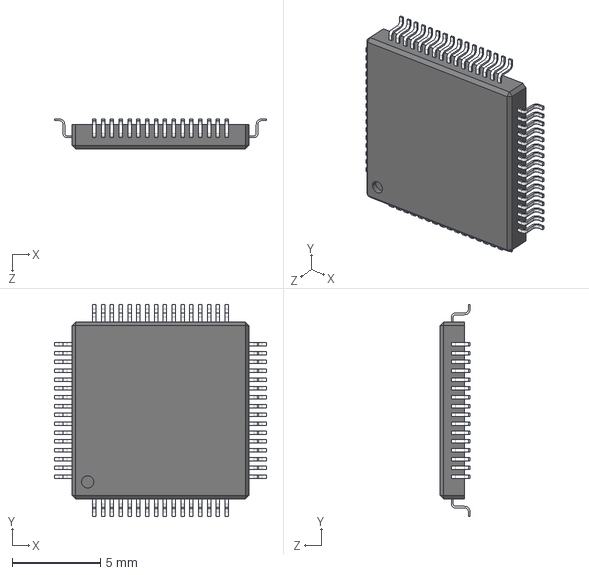
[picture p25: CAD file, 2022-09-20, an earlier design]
HARDWARE/OLIMEXINO-STM32F3-revision-B/3d/LQFP-64.step
12.0 x 12.0 x 1.71 mm

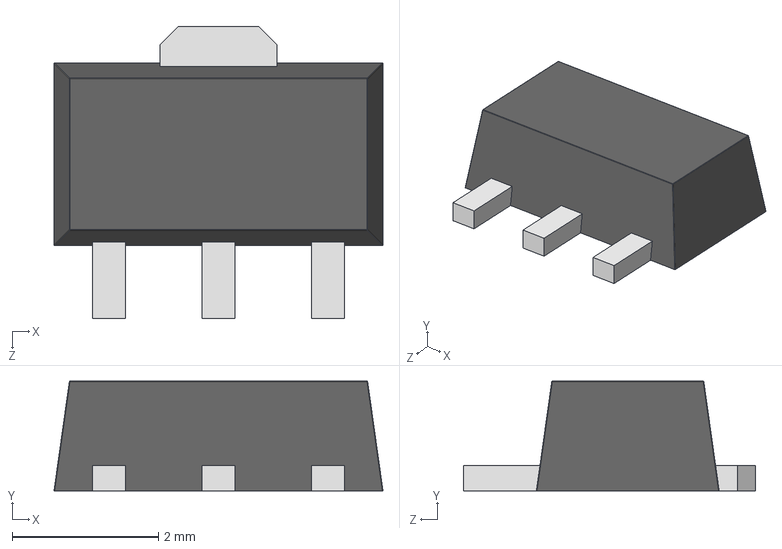
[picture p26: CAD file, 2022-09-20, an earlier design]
HARDWARE/OLIMEXINO-STM32F3-revision-B/3d/SOT-89.step
4.50 x 1.50 x 4.00 mm

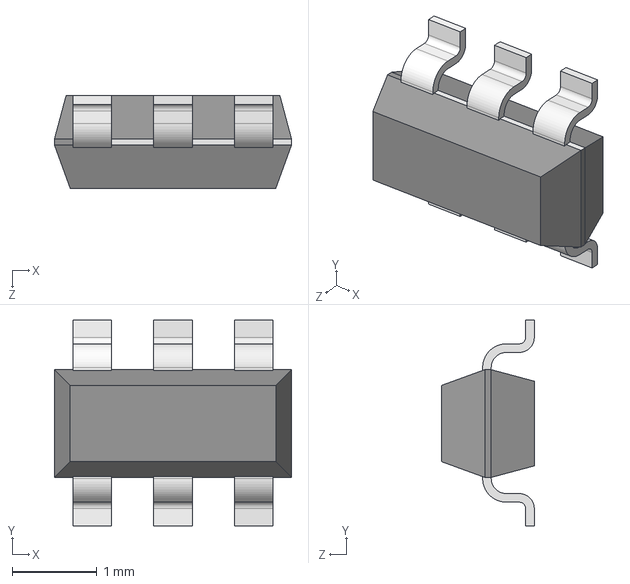
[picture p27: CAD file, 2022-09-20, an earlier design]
HARDWARE/OLIMEXINO-STM32F3-revision-B/3d/SOT-23-6.step
2.79 x 2.43 x 1.09 mm

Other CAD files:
HARDWARE/OLIMEXINO-STM32F3-revision-B/3d/L-CD43_shielded.STEP
HARDWARE/OLIMEXINO-STM32F3-revision-B/3d/pj-102ah.stp
HARDWARE/OLIMEXINO-STM32F3-revision-B/3d/Pin_Header_Straight_2x05_1.27mm.step

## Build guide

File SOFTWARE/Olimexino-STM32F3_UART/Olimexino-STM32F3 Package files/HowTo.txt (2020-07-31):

I. Download & install STM32CubeProg:
	1. Go to: 
		https://www.st.com/content/st_com/en/products/development-tools/software-development-tools/stm32-software-development-tools/stm32-programmers/stm32cubeprog.html
	2. Click the big button labeled "Get Software" - It must scroll down the web page to this area:
		STM32CubeProg 	STM32CubeProgrammer software for all STM32  Get Software
	3. Click on the Get Software button. 
	4. A zip file download shouold occur. 

	*** IMPORTANT:  The site may asks you for your name and e-mail address.
					If so, write your email and your names, then check your e-mail.
					You may receive download link.
	********************************************************************************* 

	sudo apt install openjdk-11-jre
	java -version

	5. Unzip the downloaded archive
	6. Run the "SetupSTM32CubeProgrammer-2.4.0.linux" file (double click on the file, or
					 open command-line and enter: "./SetupSTM32CubeProgrammer-2.4.0.linux)
	7. Complete the installation procedure. 
	
	Then continue with the second stage.

II. Arduino 
1. Main Menu --> File --> Preferences

Additinional Boards Manager URLs: 
https://raw.githubusercontent.com/stm32duino/BoardManagerFiles/master/STM32/package_stm_index.json

2. Main Menu --> Tools --> Board --> Boards manager...
От търсачката филтрираме за package "STM32 Cores" --> Install (200MB)

3. Main Menu --> File --> Preferences
под Additional Boards Manager URLs има линк към пътя където са добавените package-и

4. ..\packages\STM32\hardware\stm32\1.9.0
Копираме съдържанието на тази папка (board.txt, variants, libraries) в тази на package-а като overwrite-ваме вече съществуващите файлове.
По този начин ще добавим платката ни в списъка в Arduino (board.txt), описание на платката (variants) и ще редактираме библиотеката за SPI добавяйки 2 нови обекта: SPI_2; SPI_3 (libraries)

5. Рестартираме Arduino средата

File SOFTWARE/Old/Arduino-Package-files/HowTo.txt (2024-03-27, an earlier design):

In Arduino:
1. Main Menu --> File --> Preferences

Additinional Boards Manager URLs: 
https://raw.githubusercontent.com/stm32duino/BoardManagerFiles/master/STM32/package_stm_index.json

2. Main Menu --> Tools --> Board --> Boards manager...
Fitler from the search box for package "STM32 Cores" --> Install

3. Main Menu --> File --> Preferences
under Additional Boards Manager URLs there is a link to the path where are the added packages

4. ..\packages\STM32\hardware\stm32\1.9.0
Copy the contents of the folder (files board.txt, variants, libraries) in the package and overwrite the exisiting files.
Doing so adds our OLIMEXINO-STM32F3 board in the list of Arduino board selection (board.txt), description of the board (variants) and also in libraries adds two new objects: SPI_2; SPI_3 (libraries)

5. Close and re-open Arduino environment after all the setup is done.

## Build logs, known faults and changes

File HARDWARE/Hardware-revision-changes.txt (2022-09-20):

Hardware revision changes OLIMEXINO-STM32F3

---

Hardware revision C1

1. R3 changed from 23.7K_1% to 20k/1%/0402;
2. R7 changed from 10K to 330R/0402;
3. R8 changed from 20K to 680R/0402;
4. Added R36(470k/R0402).

---

Hardware revision C

Improved powerjack footprint

---

Hardware revision B

Initial release

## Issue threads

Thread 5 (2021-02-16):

Power supply

narkisg, 2021-02-16:
The Power supply is only working from 12VDC to 16.3VDC
any reason why?

narkisg, 2021-11-01:
Good for you to remember....
since then, your company admit that the boards had fault in components and change the BOM.

DanKoloff, 2021-11-16:
I don't see any changes related to the powering circuit. Maybe I am wrong. The changes are see are cosmetic (labels change, white print changes, etc). Can you provide any proof that our "company admit that the boards had fault in components and change the BOM"?

Closed 2022-10-05.

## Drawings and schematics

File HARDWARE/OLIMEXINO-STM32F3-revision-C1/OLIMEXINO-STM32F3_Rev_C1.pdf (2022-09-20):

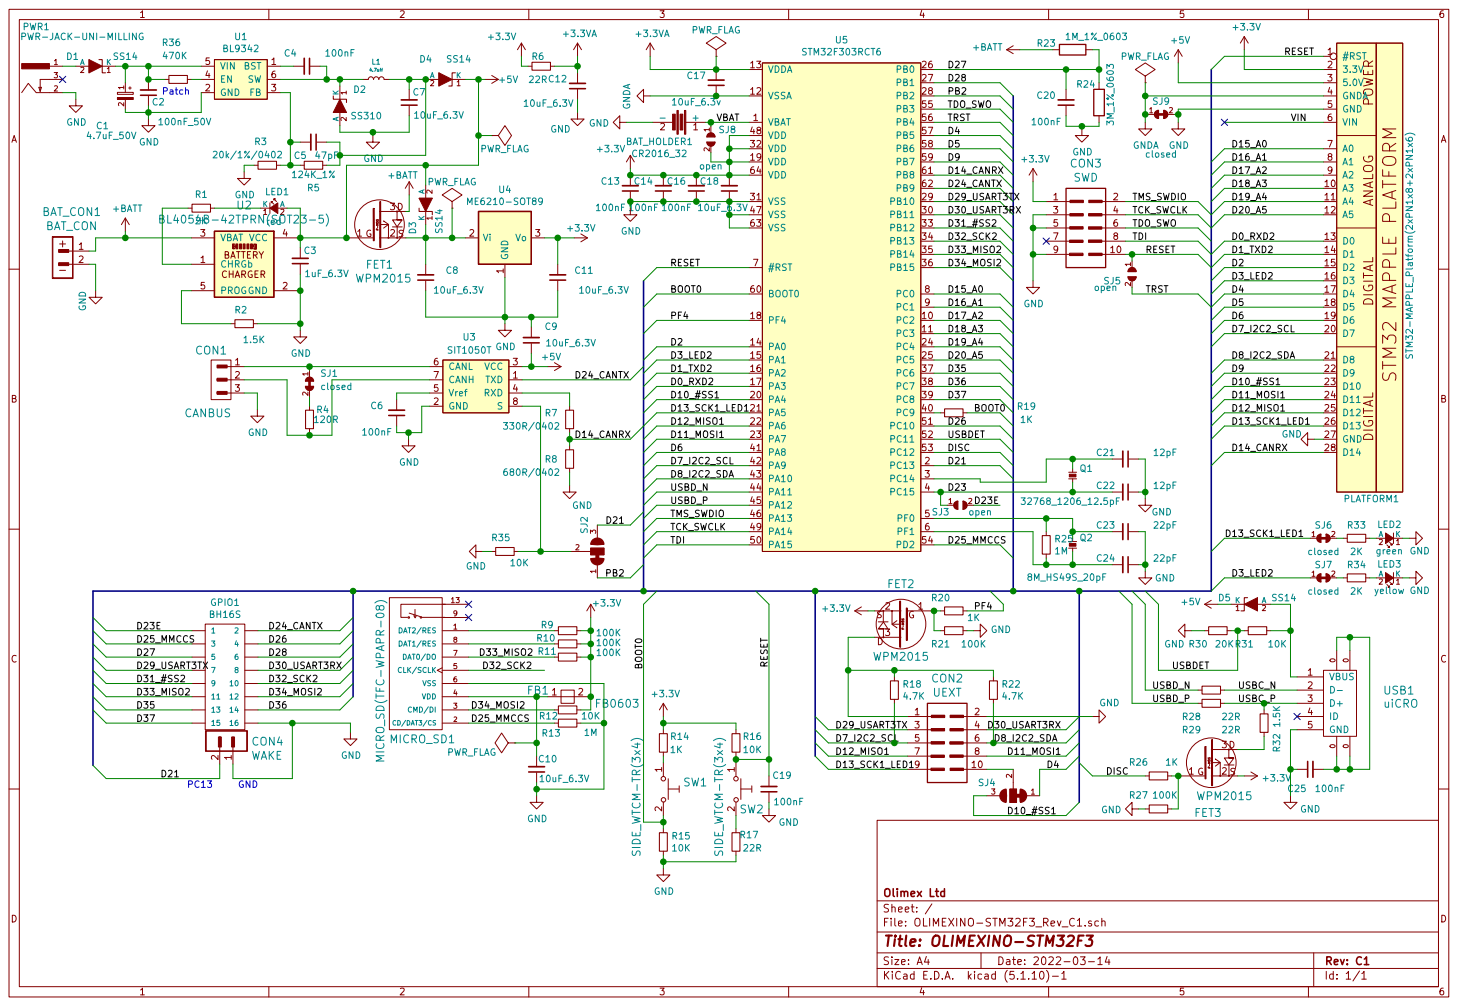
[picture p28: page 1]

3 PWR1 PWR-JACK-UNI-MILLING

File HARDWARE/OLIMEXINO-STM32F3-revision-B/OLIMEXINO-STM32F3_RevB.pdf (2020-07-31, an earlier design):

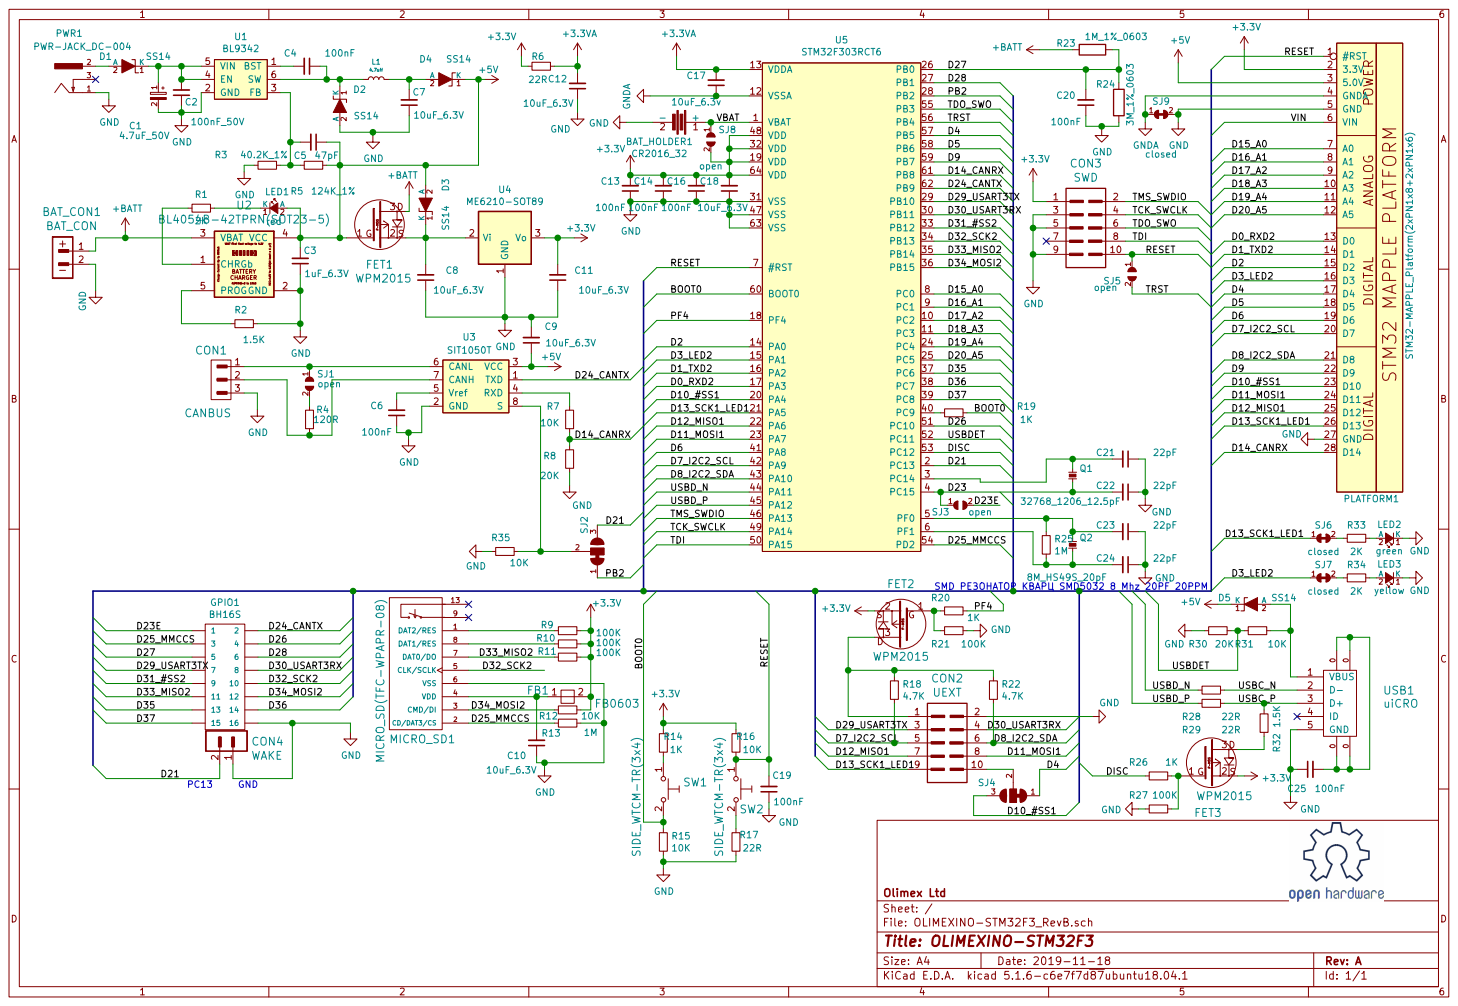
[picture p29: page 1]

5 | 6 TDO_SWO

File: OLIMEXINO-STM32F3_RevB.sch Sheet: / Olimex Ltd

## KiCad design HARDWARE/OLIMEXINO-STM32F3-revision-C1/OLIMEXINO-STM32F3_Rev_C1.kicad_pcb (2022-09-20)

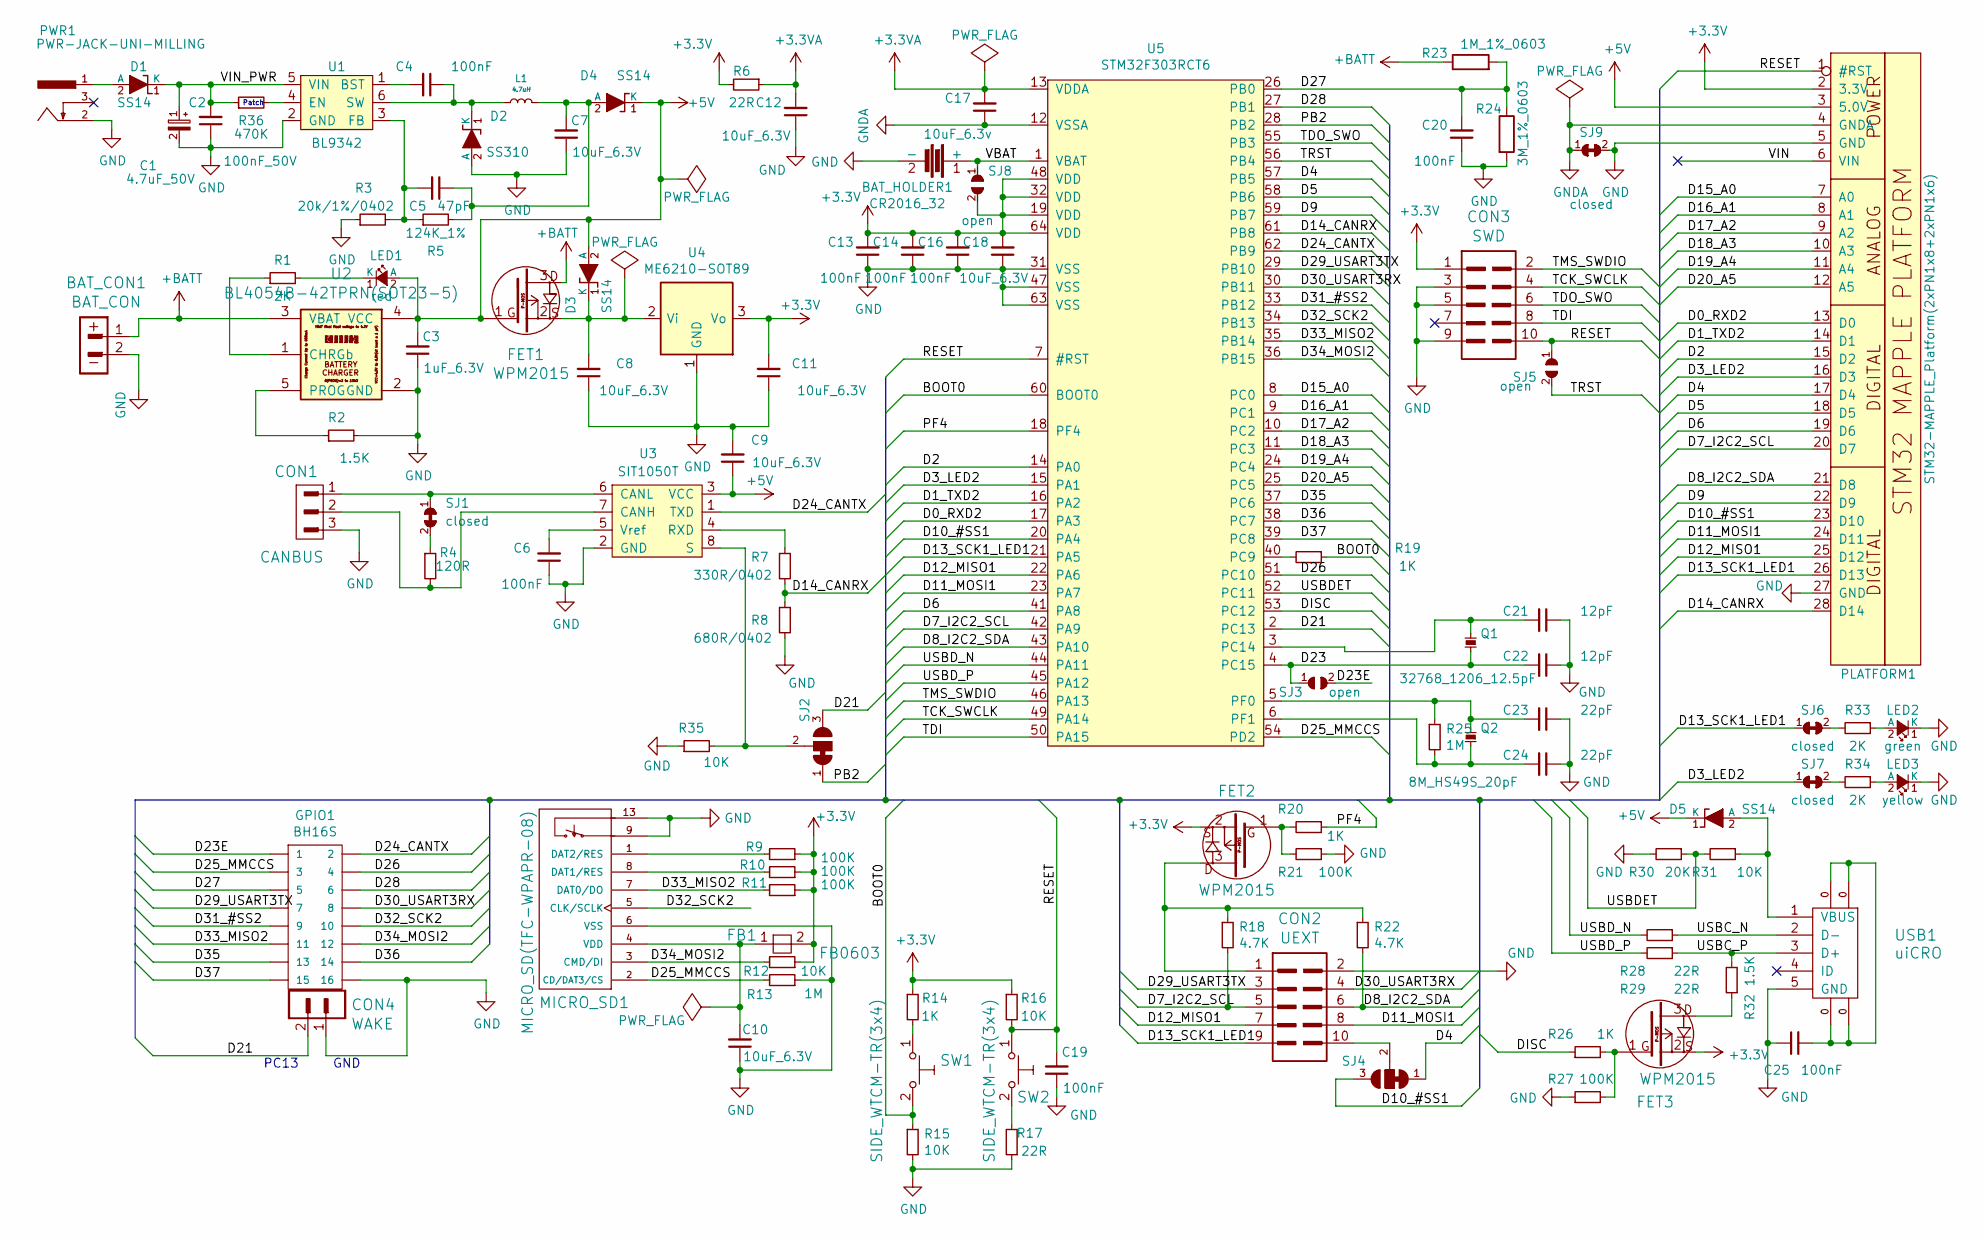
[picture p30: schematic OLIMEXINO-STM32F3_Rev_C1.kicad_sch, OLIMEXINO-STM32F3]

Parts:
BAT_CON1: BAT_CON; LIPO_BAT-CON2DW02R
BAT_HOLDER1: CR2016_32; CR2032-PTH-PLASTIC
C1: 4.7uF_50V; CPOL-RM2mm_5x9mm_PTH
C2: 100nF_50V; C_0805_5MIL_DWS
C3: 1uF_6.3V; C_0603_5MIL_DWS
C4, C6, C13, C14, C16, C19, C20, C25: 100nF; C_0402_5MIL_DWS
C5: 47pF; C_0402_5MIL_DWS
C7, C8, C9, C10, C11, C12, C18: 10uF_6.3V; C_0603_5MIL_DWS
C17: 10uF_6.3v; C_0603_5MIL_DWS
C21, C22: 12pF; C_0402_5MIL_DWS
C23, C24: 22pF; C_0402_5MIL_DWS
CON1: CANBUS; TB3-3.5mm
CON2: UEXT; UEXT_BH10R
CON3: SWD; GPH127SMT-02X05(PA-V16X-2X5-LF)
CON4: WAKE; HN1x2
D1, D3, D4, D5: SS14; SMA-KA
D2: SS310; SMA-KA
FB1: FB0603; L_0603_5MIL_DWS
FET1, FET2, FET3: WPM2015; SOT23
GPIO1: BH16S
L1: 4.7uH; CD43
LED1: red; LED_0603_KA
LED2: green; LED_0603_KA
LED3: yellow; LED_0603_KA
MICRO_SD1: MICRO_SD(TFC-WPAPR-08); MICRO_SD(TFC-WXCP11-08-LF)
PLATFORM1: STM32-MAPPLE_Platform(2xPN1x8+2xPN1x6); ARDUINO-STM32-PLATFORM
PWR1: PWR-JACK-UNI-MILLING; PWR_JACK_UNI_MILLING
Q1: 32768_1206_12.5pF; L_1206_5MIL_DWS
Q2: 8M_HS49S_20pF; Q_49U3HMS
R1, R33, R34: 2K; R_0402_5MIL_DWS
R2, R32: 1.5K; R_0402_5MIL_DWS
R3: 20k/1%/0402; R_0402_5MIL_DWS
R4: 120R; R_0402_5MIL_DWS
R5: 124K_1%; R_0402_5MIL_DWS
R6, R17, R28, R29: 22R; R_0402_5MIL_DWS
R7: 330R/0402; R_0402_5MIL_DWS
R8: 680R/0402; R_0402_5MIL_DWS
R9, R10, R11, R21, R27: 100K; R_0402_5MIL_DWS
R12, R15, R16, R31, R35: 10K; R_0402_5MIL_DWS
R13, R25: 1M; R_0402_5MIL_DWS
R14, R19, R20, R26: 1K; R_0402_5MIL_DWS
R18, R22: 4.7K; R_0402_5MIL_DWS
R23: 1M_1%_0603; R_0603_5MIL_DWS
R24: 3M_1%_0603; R_0603_5MIL_DWS
R30: 20K; R_0402_5MIL_DWS
R36: 470K; R_0402_5MIL_DWS
SJ1, SJ6, SJ7, SJ9: closed; SJ_Closed
SJ2, SJ4: SJ2W_Closed(1-2); SJ_2_SMALL_12_TIED
SJ3, SJ5, SJ8: open; SJ
SW1, SW2: SIDE_WTCM-TR(3x4); TSW34-W16PR-220
U1: BL9342; SOT23-6
U2: BL4054B-42TPRN(SOT23-5); SOT-23-5
U3: SIT1050T; SO-8
U4: ME6210-SOT89; SOT89
U5: STM32F303RCT6; LQFP64_Pitch-0.5mm_12.00x12.00x1.60mm
USB1: uiCRO; USB-MICRO_MISB-SWMM-5B_LF

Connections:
+3.3V: C11.2, C13.2, C14.2, C16.2, C18.2, CON3.1, FB1.2, FET2.2, FET3.2, PLATFORM1.2 (3.3V), R6.2, R9.1, R10.1, R11.1, R12.1, R14.1, R16.1, SJ8.2, U4.3 (Vo), U5.19 (VDD), U5.32 (VDD), U5.48 (VDD), U5.64 (VDD)
+3.3VA: C12.2, C17.2, R6.1, U5.13 (VDDA)
+5V: C3.2, C9.1, D3.2 (A), D4.1 (K), D5.1 (K), FET1.1, LED1.2 (A), PLATFORM1.3 (5.0V), U2.4 (VCC), U3.3 (VCC)
+BATT: BAT_CON1.1, FET1.3, R23.1, U2.3 (VBAT)
/BOOT0: R15.1, R19.1, SW1.2, U5.60 (BOOT0)
/D0_RXD2: PLATFORM1.13 (D0), U5.17 (PA3)
/D1_TXD2: PLATFORM1.14 (D1), U5.16 (PA2)
/D2: PLATFORM1.15 (D2), U5.14 (PA0)
/D3_LED2: PLATFORM1.16 (D3), SJ7.1, U5.15 (PA1)
/D4: PLATFORM1.17 (D4), SJ4.1, U5.57 (PB5)
/D5: PLATFORM1.18 (D5), U5.58 (PB6)
/D6: PLATFORM1.19 (D6), U5.41 (PA8)
/D7_I2C2_SCL: CON2.5, PLATFORM1.20 (D7), R18.2, U5.42 (PA9)
/D8_I2C2_SDA: CON2.6, PLATFORM1.21 (D8), R22.2, U5.43 (PA10)
/D9: PLATFORM1.22 (D9), U5.59 (PB7)
/D10_#SS1: PLATFORM1.23 (D10), SJ4.3, U5.20 (PA4)
/D11_MOSI1: CON2.8, PLATFORM1.24 (D11), U5.23 (PA7)
/D12_MISO1: CON2.7, PLATFORM1.25 (D12), U5.22 (PA6)
/D13_SCK1_LED1: CON2.9, PLATFORM1.26 (D13), SJ6.1, U5.21 (PA5)
/D14_CANRX: PLATFORM1.28 (D14), R7.2, R8.1, U5.61 (PB8)
/D15_A0: PLATFORM1.7 (A0), U5.8 (PC0)
/D16_A1: PLATFORM1.8 (A1), U5.9 (PC1)
/D17_A2: PLATFORM1.9 (A2), U5.10 (PC2)
/D18_A3: PLATFORM1.10 (A3), U5.11 (PC3)
/D19_A4: PLATFORM1.11 (A4), U5.24 (PC4)
/D20_A5: PLATFORM1.12 (A5), U5.25 (PC5)
/D21: CON4.2, SJ2.3, U5.2 (PC13)
/D23: C22.2, Q1.1, SJ3.1, U5.4 (PC15)
/D23E: GPIO1.1, SJ3.2
/D24_CANTX: GPIO1.2, U3.1 (TXD), U5.62 (PB9)
/D25_MMCCS: GPIO1.3, MICRO_SD1.2 (CD/DAT3/CS), R13.2, U5.54 (PD2)
/D26: GPIO1.4, U5.51 (PC10)
/D27: C20.2, GPIO1.5, R23.2, R24.1, U5.26 (PB0)
/D28: GPIO1.6, U5.27 (PB1)
/D29_USART3TX: CON2.3, GPIO1.7, U5.29 (PB10)
/D30_USART3RX: CON2.4, GPIO1.8, U5.30 (PB11)
/D31_#SS2: GPIO1.9, U5.33 (PB12)
/D32_SCK2: GPIO1.10, MICRO_SD1.5 (CLK/SCLK), U5.34 (PB13)
/D33_MISO2: GPIO1.11, MICRO_SD1.7 (DAT0/DO), R11.2, U5.35 (PB14)
/D34_MOSI2: GPIO1.12, MICRO_SD1.3 (CMD/DI), R12.2, U5.36 (PB15)
/D35: GPIO1.13, U5.37 (PC6)
/D36: GPIO1.14, U5.38 (PC7)
/D37: GPIO1.15, U5.39 (PC8)
/DISC: R26.1, U5.53 (PC12)
/PB2: SJ2.1, U5.28 (PB2)
/PF4: R20.1, U5.18 (PF4)
/RESET: C19.2, CON3.10, PLATFORM1.1 (#RST), R16.2, SJ5.1, SW2.1, U5.7 (#RST)
/TCK_SWCLK: CON3.4, U5.49 (PA14)
/TDI: CON3.8, U5.50 (PA15)
/TDO_SWO: CON3.6, U5.55 (PB3)
/TMS_SWDIO: CON3.2, U5.46 (PA13)
/TRST: SJ5.2, U5.56 (PB4)
/USBC_N: R28.1, USB1.2 (D-)
/USBC_P: R29.1, R32.2, USB1.3 (D+)
/USBDET: R30.1, R31.2, U5.52 (PC11)
/USBD_N: R28.2, U5.44 (PA11)
/USBD_P: R29.2, U5.45 (PA12)
/VBAT: BAT_HOLDER1.1 (+), SJ8.1, U5.1 (VBAT)
/VIN: PLATFORM1.6 (VIN)
/VIN_PWR: C1.1 (+), C2.2, D1.1 (K), R36.1, U1.5 (VIN)
GND: BAT_CON1.2, BAT_HOLDER1.2 (-), C1.2 (-), C2.1, C3.1, C6.1, C7.1, C8.1, C9.2, C10.1, C11.1, C12.1, C13.1, C14.1, C16.1, C18.1, C19.1, C20.1, C21.1, C22.1, C23.1, C24.1, C25.1, CON1.3, CON2.2, CON3.3, CON3.5, CON3.9, CON4.1, D2.2 (A), GPIO1.16, LED2.1 (K), LED3.1 (K), MICRO_SD1.6 (VSS), MICRO_SD1.9, MICRO_SD1.10, MICRO_SD1.11, MICRO_SD1.12, MICRO_SD1.13, PLATFORM1.5 (GND), PLATFORM1.27 (GND), PWR1.2 (-), R2.2, R3.1, R8.2, R13.1, R15.2, R17.1, R21.1, R24.2, R27.1, R30.2, R35.1, SJ9.2, U1.2 (GND), U2.2 (GND), U3.2 (GND), U4.1 (GND), U5.31 (VSS), U5.47 (VSS), U5.63 (VSS), USB1.5 (GND)
GNDA: C17.1, PLATFORM1.4 (GNDA), SJ9.1, U5.12 (VSSA)
unnamed: C4.1, D2.1 (K), L1.1, U1.6 (SW)
unnamed: C4.2, U1.1 (BST)
unnamed: C5.1, C7.2, D4.2 (A), L1.2, R5.2
unnamed: C5.2, R3.2, R5.1, U1.3 (FB)
unnamed: C6.2, U3.5 (Vref)
unnamed: C8.2, D3.1 (K), FET1.2, U4.2 (Vi)
unnamed: C10.2, FB1.1, MICRO_SD1.4 (VDD)
unnamed: C21.2, Q1.2, U5.3 (PC14)
unnamed: C23.2, Q2.2, R25.1, U5.5 (PF0)
unnamed: C24.2, Q2.1, R25.2, U5.6 (PF1)
unnamed: C25.2, USB1.0
unnamed: CON1.1, SJ1.1, U3.6 (CANL)
unnamed: CON1.2, R4.2, U3.7 (CANH)
unnamed: CON2.1, FET2.3, R18.1, R22.1
unnamed: CON2.10, SJ4.2
unnamed: D1.2 (A), PWR1.1 (+)
unnamed: D5.2 (A), R31.1, USB1.1 (VBUS)
unnamed: FET2.1, R20.2, R21.2
unnamed: FET3.1, R26.2, R27.2
unnamed: FET3.3, R32.1
unnamed: LED1.1 (K), R1.2
unnamed: LED2.2 (A), R33.1
unnamed: LED3.2 (A), R34.1
unnamed: MICRO_SD1.1 (DAT2/RES), R9.2
unnamed: MICRO_SD1.8 (DAT1/RES), R10.2
unnamed: R1.1, U2.1 (CHRGb)
unnamed: R2.1, U2.5 (PROG)
unnamed: R4.1, SJ1.2
unnamed: R7.1, U3.4 (RXD)
unnamed: R14.2, SW1.1
unnamed: R17.2, SW2.2
unnamed: R19.2, U5.40 (PC9)
unnamed: R33.2, SJ6.2
unnamed: R34.2, SJ7.2
unnamed: R35.2, SJ2.2, U3.8 (S)
unnamed: R36.2, U1.4 (EN)

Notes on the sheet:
PC13 GND
Patch

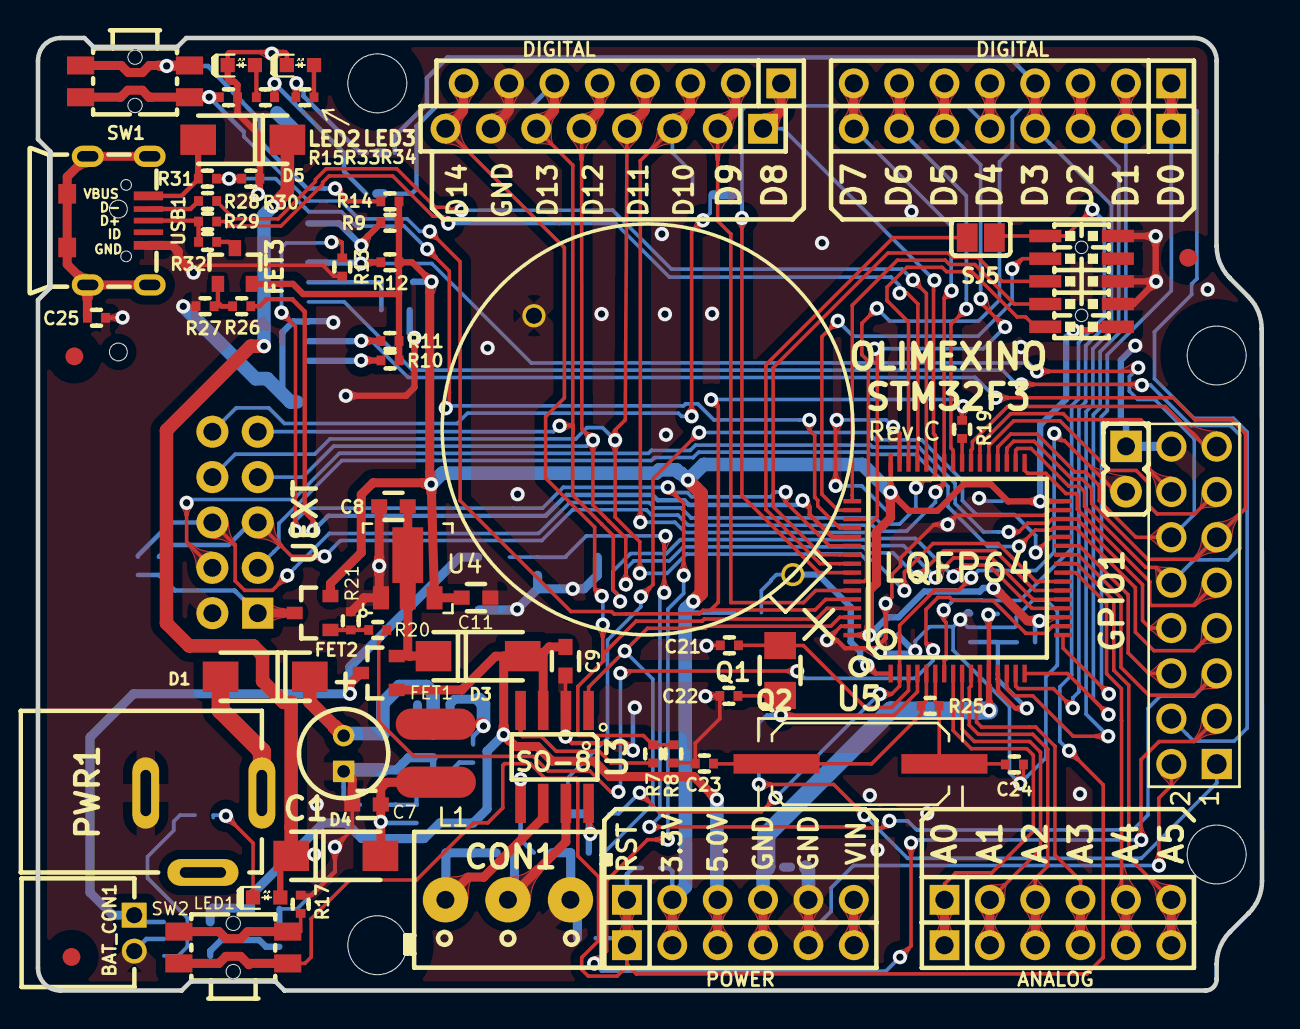
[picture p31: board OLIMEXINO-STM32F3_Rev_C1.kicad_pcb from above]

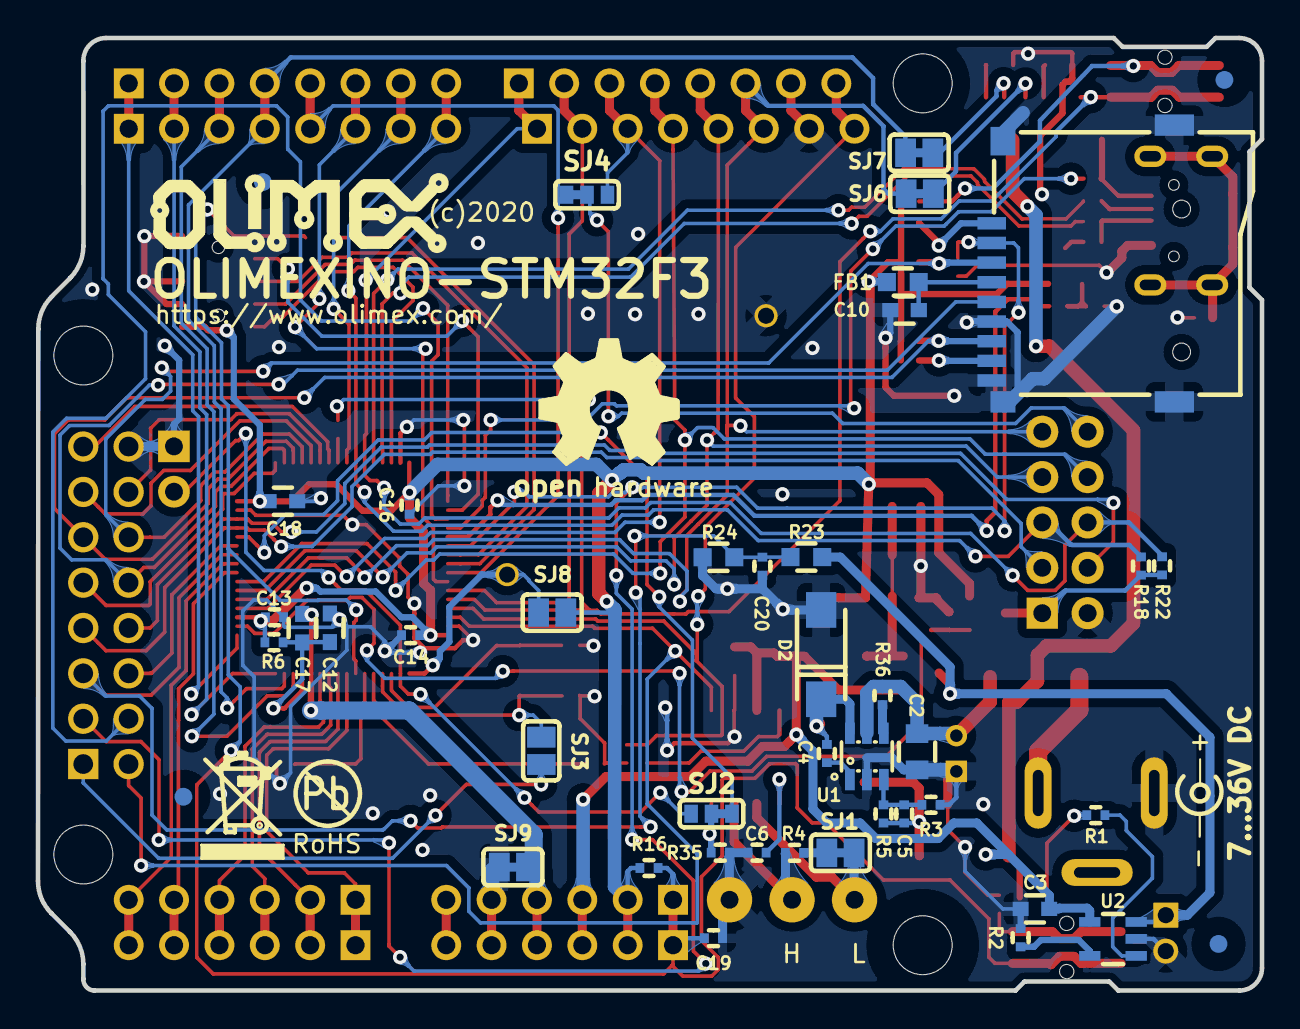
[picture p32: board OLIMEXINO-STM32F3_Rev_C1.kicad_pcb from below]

Board: 2 copper layers, 68.5 x 53.3 mm, 109 parts (44 on the bottom side), 97 nets.

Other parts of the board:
Ref*: Val**; Fiducial1x3_transp
Ref*#2, Ref*#3, Ref*#4, Ref*#5, Ref*#6, Ref*#7: Val**; Fiducial1x3_transp

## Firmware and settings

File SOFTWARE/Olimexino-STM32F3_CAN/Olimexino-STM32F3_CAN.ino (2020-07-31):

/* Example from https://github.com/nopnop2002/Arduino-STM32-CAN for STM32F303
 *  Works with 2 Olimexino-STM32F3 board with closed terminal jumpers (SJ1)
*/

#define DEBUG 0

enum BITRATE{CAN_50KBPS, CAN_100KBPS, CAN_125KBPS, CAN_250KBPS, CAN_500KBPS, CAN_1000KBPS};

typedef struct
{
  uint32_t id;
  uint8_t  data[8];
  uint8_t  len;
} CAN_msg_t;

typedef const struct
{
  uint8_t TS2;
  uint8_t TS1;
  uint8_t BRP;
} CAN_bit_timing_config_t;

CAN_bit_timing_config_t can_configs[6] = {{2, 13, 45}, {2, 15, 20}, {2, 13, 18}, {2, 13, 9}, {2, 15, 4}, {2, 15, 2}};

/**
 * Print registers.
*/ 
void printRegister(char * buf, uint32_t reg) {
  if (DEBUG == 0) return;
  Serial.print(buf);
  Serial.print(reg, HEX);
  Serial.println();
}

/**
 * Initializes the CAN GPIO registers.
 *
 * @params: addr    - Specified GPIO register address.
 * @params: index   - Specified GPIO index.
 * @params: speed   - Specified OSPEEDR register value.(Optional)
 *
 */
void CANSetGpio(GPIO_TypeDef * addr, uint8_t index, uint8_t speed = 3) {
    uint8_t _index2 = index * 2;
    uint8_t _index4 = index * 4;
    uint8_t ofs = 0;
    uint8_t setting;

    if (index > 7) {
      _index4 = (index - 8) * 4;
      ofs = 1;
    }

    uint32_t mask;
    printRegister("GPIO_AFR(b)=", addr->AFR[1]);
    mask = 0xF << _index4;
    addr->AFR[ofs]  &= ~mask;         // Reset alternate function
    setting = 0x9;                    // AF9
    mask = setting << _index4;
    addr->AFR[ofs]  |= mask;          // Set alternate function
    printRegister("GPIO_AFR(a)=", addr->AFR[1]);

    printRegister("GPIO_MODER(b)=", addr->MODER);
    mask = 0x3 << _index2;
    addr->MODER   &= ~mask;           // Reset mode
    setting = 0x2;                    // Alternate function mode
    mask = setting << _index2;
    addr->MODER   |= mask;            // Set mode
    printRegister("GPIO_MODER(a)=", addr->MODER);

    printRegister("GPIO_OSPEEDR(b)=", addr->OSPEEDR);
    mask = 0x3 << _index2;
    addr->OSPEEDR &= ~mask;           // Reset speed
    setting = speed;
    mask = setting << _index2;
    addr->OSPEEDR |= mask;            // Set speed
    printRegister("GPIO_OSPEEDR(a)=", addr->OSPEEDR);

    printRegister("GPIO_OTYPER(b)=", addr->OTYPER);
    mask = 0x1 << index;
    addr->OTYPER  &= ~mask;           // Reset Output push-pull
    printRegister("GPIO_OTYPER(a)=", addr->OTYPER);

    printRegister("GPIO_PUPDR(b)=", addr->PUPDR);
    mask = 0x3 << _index2;
    addr->PUPDR   &= ~mask;           // Reset port pull-up/pull-down
    printRegister("GPIO_PUPDR(a)=", addr->PUPDR);
}


/**
 * Initializes the CAN filter registers.
 *
 * @preconditions   - This register can be written only when the filter initialization mode is set (FINIT=1) in the CAN_FMR register.
 * @params: index   - Specified filter index. index 27:14 are available in connectivity line devices only.
 * @params: scale   - Select filter scale.
 *                    0: Dual 16-bit scale configuration
 *                    1: Single 32-bit scale configuration
 * @params: mode    - Select filter mode.
 *                    0: Two 32-bit registers of filter bank x are in Identifier Mask mode
 *                    1: Two 32-bit registers of filter bank x are in Identifier List mode
 * @params: fifo    - Select filter assigned.
 *                    0: Filter assigned to FIFO 0
 *                    1: Filter assigned to FIFO 1
 * @params: bank1   - Filter bank register 1
 * @params: bank2   - Filter bank register 2
 *
 */
void CANSetFilter(uint8_t index, uint8_t scale, uint8_t mode, uint8_t fifo, uint32_t bank1, uint32_t bank2) {
  if (index > 27) return;

  CAN1->FA1R &= ~(0x1UL<<index);               // Deactivate filter0

  if (scale == 0) {
    CAN1->FS1R &= ~(0x1UL<<index);             // Set filter to Dual 16-bit scale configuration
  } else {
    CAN1->FS1R |= (0x1UL<<index);              // Set filter to single 32 bit configuration
  }
    if (mode == 0) {
    CAN1->FM1R &= ~(0x1UL<<index);             // Set filter to Mask mode
  } else {
    CAN1->FM1R |= (0x1UL<<index);              // Set filter to List mode
  }

  if (fifo == 0) {
    CAN1->FFA1R &= ~(0x1UL<<index);            // Set filter assigned to FIFO 0
  } else {
    CAN1->FFA1R |= (0x1UL<<index);             // Set filter assigned to FIFO 1
  }

  CAN1->sFilterRegister[index].FR1 = bank1;    // Set filter bank registers1
  CAN1->sFilterRegister[index].FR2 = bank2;    // Set filter bank registers2

  CAN1->FA1R |= (0x1UL<<index);                // Activate filter

}

    
/**
 * Initializes the CAN controller with specified bit rate.
 *
 * @params: bitrate - Specified bitrate. If this value is not one of the defined constants, bit rate will be defaulted to 125KBS
 * @params: remap   - Select CAN port. 
 *                    =0:CAN_RX mapped to PA11, CAN_TX mapped to PA12
 *                    =1:Not used
 *                    =2:CAN_RX mapped to PB8, CAN_TX mapped to PB9 (not available on 36-pin package)
 *                    =3:CAN_RX mapped to PD0, CAN_TX mapped to PD1 (available on 100-pin and 144-pin package)
 *
 */
bool CANInit(enum BITRATE bitrate, int remap)
{
  // Reference manual
  // https://www.st.com/content/ccc/resource/technical/document/reference_manual/4a/19/6e/18/9d/92/43/32/DM00043574.pdf/files/DM00043574.pdf/jcr:content/translations/en.D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

  RCC->APB1ENR |= 0x2000000UL;          // Enable CAN clock 

  if (remap == 0) {
    RCC->AHBENR |= 0x20000UL;           // Enable GPIOA clock 
    CANSetGpio(GPIOA, 11);              // Set PA11
    CANSetGpio(GPIOA, 12);              // Set PA12
  }

  if (remap == 2) {
    RCC->AHBENR |= 0x40000UL;           // Enable GPIOB clock 
    CANSetGpio(GPIOB, 8);               // Set PB8
    CANSetGpio(GPIOB, 9);               // Set PB9
  }

  if (remap == 3) {
    RCC->AHBENR |= 0x100000UL;          // Enable GPIOD clock 
    CANSetGpio(GPIOD, 0);               // Set PD0
    CANSetGpio(GPIOD, 1);               // Set PD1
  }

  CAN1->MCR |= 0x1UL;                   // Set CAN to Initialization mode 
  while (!(CAN1->MSR & 0x1UL));         // Wait for Initialization mode

  //CAN1->MCR = 0x51UL;                 // Hardware initialization(No automatic retransmission)
  CAN1->MCR = 0x41UL;                   // Hardware initialization(With automatic retransmission)

  // Set bit rates 
  CAN1->BTR &= ~(((0x03) << 24) | ((0x07) << 20) | ((0x0F) << 16) | (0x1FF)); 
  CAN1->BTR |=  (((can_configs[bitrate].TS2-1) & 0x07) << 20) | (((can_configs[bitrate].TS1-1) & 0x0F) << 16) | ((can_configs[bitrate].BRP-1) & 0x1FF);

  // Configure Filters to default values
  CAN1->FMR  |=   0x1UL;                // Set to filter initialization mode
  CAN1->FMR  &= 0xFFFFC0FF;             // Clear CAN2 start bank

  // bxCAN has 28 filters.
  // These filters are used for both CAN1 and CAN2.
  // STM32F303 has only CAN1, so all 28 are used for CAN1
  CAN1->FMR  |= 0x1C << 8;              // Assign all filters to CAN1

  // Set fileter 0
  // Single 32-bit scale configuration 
  // Two 32-bit registers of filter bank x are in Identifier Mask mode
  // Filter assigned to FIFO 0 
  // Filter bank register to all 0
  CANSetFilter(0, 1, 0, 0, 0x0UL, 0x0UL); 

  CAN1->FMR   &= ~(0x1UL);              // Deactivate initialization mode

  uint16_t TimeoutMilliseconds = 1000;
  bool can1 = false;
  CAN1->MCR   &= ~(0x1UL);              // Require CAN1 to normal mode 

  // Wait for normal mode
  // If the connection is not correct, it will not return to normal mode.
  for (uint16_t wait_ack = 0; wait_ack < TimeoutMilliseconds; wait_ack++) {
    if ((CAN1->MSR & 0x1UL) == 0) {
      can1 = true;
      break;
    }
    delayMicroseconds(1000);
  }
  //Serial.print("can1=");
  //Serial.println(can1);
  if (can1) {
    Serial.println("CAN1 initialize ok");
  } else {
    Serial.println("CAN1 initialize fail!!");
    return false;
  }
  return true; 
}


#define STM32_CAN_TIR_TXRQ              (1U << 0U)  // Bit 0: Transmit Mailbox Request
#define STM32_CAN_RIR_RTR               (1U << 1U)  // Bit 1: Remote Transmission Request
#define STM32_CAN_RIR_IDE               (1U << 2U)  // Bit 2: Identifier Extension
#define STM32_CAN_TIR_RTR               (1U << 1U)  // Bit 1: Remote Transmission Request
#define STM32_CAN_TIR_IDE               (1U << 2U)  // Bit 2: Identifier Extension

#define CAN_EXT_ID_MASK                 0x1FFFFFFFU
#define CAN_STD_ID_MASK                 0x000007FFU
#define CAN_FRAME_RTR                   (1UL << 30U) // Remote transmission
 
/**
 * Decodes CAN messages from the data registers and populates a 
 * CAN message struct with the data fields.
 * 
 * @preconditions     - A valid CAN message is received
 * @params CAN_rx_msg - CAN message structure for reception
 * 
 */
void CANReceive(CAN_msg_t* CAN_rx_msg)
{
  uint32_t id = CAN1->sFIFOMailBox[0].RIR;
  if ((id & STM32_CAN_RIR_IDE) == 0) { // Standard frame format
      CAN_rx_msg->id = (CAN_STD_ID_MASK & (id >> 21U));
  } 
  else {                               // Extended frame format
      CAN_rx_msg->id = (CAN_EXT_ID_MASK & (id >> 3U));
  }

  if ((id & STM32_CAN_RIR_RTR) != 0) {
      CAN_rx_msg->id |= CAN_FRAME_RTR;
  }

  
  CAN_rx_msg->len = (CAN1->sFIFOMailBox[0].RDTR) & 0xFUL;
  
  CAN_rx_msg->data[0] = 0xFFUL &  CAN1->sFIFOMailBox[0].RDLR;
  CAN_rx_msg->data[1] = 0xFFUL & (CAN1->sFIFOMailBox[0].RDLR >> 8);
  CAN_rx_msg->data[2] = 0xFFUL & (CAN1->sFIFOMailBox[0].RDLR >> 16);
  CAN_rx_msg->data[3] = 0xFFUL & (CAN1->sFIFOMailBox[0].RDLR >> 24);
  CAN_rx_msg->data[4] = 0xFFUL &  CAN1->sFIFOMailBox[0].RDHR;
  CAN_rx_msg->data[5] = 0xFFUL & (CAN1->sFIFOMailBox[0].RDHR >> 8);
  CAN_rx_msg->data[6] = 0xFFUL & (CAN1->sFIFOMailBox[0].RDHR >> 16);
  CAN_rx_msg->data[7] = 0xFFUL & (CAN1->sFIFOMailBox[0].RDHR >> 24);

  // Release FIFO 0 output mailbox.
  // Make the next incoming message available.
  CAN1->RF0R |= 0x20UL;
}
 
/**
 * Encodes CAN messages using the CAN message struct and populates the 
 * data registers with the sent.
 * 
 * @params CAN_tx_msg - CAN message structure for transmission
 * 
 */
void CANSend(CAN_msg_t* CAN_tx_msg)
{
  volatile int count = 0;

  uint32_t out = 0;
  if (CAN_tx_msg->id > CAN_STD_ID_MASK) { // Extended frame format
      out = ((CAN_tx_msg->id & CAN_EXT_ID_MASK) << 3U) | STM32_CAN_TIR_IDE;
  }
  else {                                  // Standard frame format
      out = ((CAN_tx_msg->id & CAN_STD_ID_MASK) << 21U);
  }

  // Remote frame
  if (CAN_tx_msg->id & CAN_FRAME_RTR) {
      out |= STM32_CAN_TIR_RTR;
  }

  CAN1->sTxMailBox[0].TDTR &= ~(0xF);
  CAN1->sTxMailBox[0].TDTR |= CAN_tx_msg->len & 0xFUL;
  
  CAN1->sTxMailBox[0].TDLR  = (((uint32_t) CAN_tx_msg->data[3] << 24) |
                               ((uint32_t) CAN_tx_msg->data[2] << 16) |
                               ((uint32_t) CAN_tx_msg->data[1] <<  8) |
                               ((uint32_t) CAN_tx_msg->data[0]      ));
  CAN1->sTxMailBox[0].TDHR  = (((uint32_t) CAN_tx_msg->data[7] << 24) |
                               ((uint32_t) CAN_tx_msg->data[6] << 16) |
                               ((uint32_t) CAN_tx_msg->data[5] <<  8) |
                               ((uint32_t) CAN_tx_msg->data[4]      ));

  // Send Go
  CAN1->sTxMailBox[0].TIR = out | STM32_CAN_TIR_TXRQ;

  // Wait until the mailbox is empty
  while(CAN1->sTxMailBox[0].TIR & 0x1UL && count++ < 1000000);
   
  // The mailbox don't becomes empty while loop
  if (CAN1->sTxMailBox[0].TIR & 0x1UL) {
    Serial.println("Send Fail");
    Serial.println(CAN1->ESR);
    Serial.println(CAN1->MSR);
    Serial.println(CAN1->TSR);
  }
}

 /**
 * Returns whether there are CAN messages available.
 *
 * @returns If pending CAN messages are in the CAN controller
 *
 */
uint8_t CANMsgAvail(void)
{
  // Check for pending FIFO 0 messages
  return CAN1->RF0R & 0x3UL;
}


uint8_t counter = 0;
unsigned long previousMillis = 0;     // stores last time output was updated
const long interval = 1000;           // transmission interval (milliseconds)

void setup() {
  Serial.begin(115200);
  //bool ret = CANInit(CAN_1000KBPS, 0);  // CAN_RX mapped to PA11, CAN_TX mapped to PA12
  bool ret = CANInit(CAN_1000KBPS, 2);  // CAN_RX mapped to PB8, CAN_TX mapped to PB9
  //bool ret = CANInit(CAN_1000KBPS, 3);  // CAN_RX mapped to PD0, CAN_TX mapped to PD1
  if (!ret) while(true);
}

void loop() {
  CAN_msg_t CAN_TX_msg;
  CAN_msg_t CAN_RX_msg;
   
  CAN_TX_msg.data[0] = counter;
  CAN_TX_msg.data[1] = 0x01;
  CAN_TX_msg.data[2] = 0x02;
  CAN_TX_msg.data[3] = 0x03;
  CAN_TX_msg.data[4] = 0x04;
  CAN_TX_msg.data[5] = 0x05;
  CAN_TX_msg.data[6] = 0x06;
  CAN_TX_msg.data[7] = 0x07;
  CAN_TX_msg.len = 8;

  unsigned long currentMillis = millis();
  if (currentMillis - previousMillis >= interval) {
    previousMillis = currentMillis;
    if ( ( counter % 2) == 0) {
        CAN_TX_msg.id = 0x1032F303;
    } else {
        CAN_TX_msg.id = 0x103;
    }
    CANSend(&CAN_TX_msg);
    counter++;
  }
  
  if(CANMsgAvail()) {
    CANReceive(&CAN_RX_msg);

    if (CAN_RX_msg.id > 0x7ff) {
      Serial.print("Extended ID: 0x");
      if (CAN_RX_msg.id < 0x10000000) Serial.print("0");
      if (CAN_RX_msg.id < 0x1000000) Serial.print("00");
      if (CAN_RX_msg.id < 0x100000) Serial.print("000");
      if (CAN_RX_msg.id < 0x10000) Serial.print("0000");
      Serial.print(CAN_RX_msg.id, HEX);
    } else {
      Serial.print("Standard ID: 0x");
      if (CAN_RX_msg.id < 0x100) Serial.print("0");
      if (CAN_RX_msg.id < 0x10) Serial.print("00");
      Serial.print(CAN_RX_msg.id, HEX);
      Serial.print("     ");
    }

    Serial.print(" DLC: ");
    Serial.print(CAN_RX_msg.len);
    Serial.print(" Data: ");
    for(int i=0; i<CAN_RX_msg.len; i++) {
      Serial.print("0x"); 
      Serial.print(CAN_RX_msg.data[i], HEX); 
      if (i != (CAN_RX_msg.len-1))  Serial.print(" ");
    }
    Serial.println();
  }
    
  

}

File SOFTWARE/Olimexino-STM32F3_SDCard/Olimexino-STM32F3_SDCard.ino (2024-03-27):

/*
  SD card test

  This example shows how use the utility libraries on which the'
  SD library is based in order to get info about your SD card.
  Very useful for testing a card when you're not sure whether its working or not.

  created  28 Mar 2011
  by Limor Fried
  modified 9 Apr 2012
  by Tom Igoe
*/
// include the SD library:
#include <SPI.h>
#include <SD.h>

// set up variables using the SD utility library functions:
Sd2Card card;
SdVolume volume;
SdFile root;

const int chipSelect = 25;

void setup() {
  // reassigning the pins for the SPI object to hardware SPI2 pins
  SPI.setMOSI (PIN_SPI2_MOSI);
  SPI.setMISO (PIN_SPI2_MISO);
  SPI.setSCLK (PIN_SPI2_SCK);
  
  // Open serial communications and wait for port to open:
  Serial.begin(115200);
  while (!Serial) {
    ; // wait for serial port to connect. Needed for native USB port only
  }


  Serial.print("\nInitializing SD card...");

  // we'll use the initialization code from the utility libraries
  // since we're just testing if the card is working!
  if (!card.init(SPI_HALF_SPEED, chipSelect)) {
    Serial.println("initialization failed. Things to check:");
    Serial.println("* is a card inserted?");
    Serial.println("* is your wiring correct?");
    Serial.println("* did you change the chipSelect pin to match your shield or module?");
    while (1);
  } else {
    Serial.println("Wiring is correct and a card is present.");
  }

  // print the type of card
  Serial.println();
  Serial.print("Card type:         ");
  switch (card.type()) {
    case SD_CARD_TYPE_SD1:
      Serial.println("SD1");
      break;
    case SD_CARD_TYPE_SD2:
      Serial.println("SD2");
      break;
    case SD_CARD_TYPE_SDHC:
      Serial.println("SDHC");
      break;
    default:
      Serial.println("Unknown");
  }

  // Now we will try to open the 'volume'/'partition' - it should be FAT16 or FAT32
  if (!volume.init(card)) {
    Serial.println("Could not find FAT16/FAT32 partition.\nMake sure you've formatted the card");
    while (1);
  }

  Serial.print("Clusters:          ");
  Serial.println(volume.clusterCount());
  Serial.print("Blocks x Cluster:  ");
  Serial.println(volume.blocksPerCluster());

  Serial.print("Total Blocks:      ");
  Serial.println(volume.blocksPerCluster() * volume.clusterCount());
  Serial.println();

  // print the type and size of the first FAT-type volume
  uint32_t volumesize;
  Serial.print("Volume type is:    FAT");
  Serial.println(volume.fatType(), DEC);

  volumesize = volume.blocksPerCluster();    // clusters are collections of blocks
  volumesize *= volume.clusterCount();       // we'll have a lot of clusters
  volumesize /= 2;                           // SD card blocks are always 512 bytes (2 blocks are 1KB)
  Serial.print("Volume size (Kb):  ");
  Serial.println(volumesize);
  Serial.print("Volume size (Mb):  ");
  volumesize /= 1024;
  Serial.println(volumesize);
  Serial.print("Volume size (Gb):  ");
  Serial.println((float)volumesize / 1024.0);

  Serial.println("\nFiles found on the card (name, date and size in bytes): ");
  root.openRoot(volume);

  // list all files in the card with date and size
  root.ls(LS_R | LS_DATE | LS_SIZE);
}

void loop(void) {
}

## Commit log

2020-07-31 initial upload
    [Cap_PTH_6_3x11x2_5mm.step, DO-214AC_SMA.step, Header_right_angle_10way(2x5).step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]
2022-09-22 Update
    Improved STM32F3 manual and added GD32F3 bootloader and blink demo
2024-03-27 Examples update
    Examples updated to work with the latest version (at the moment of this commit 2.7.1) of the STM32-duino package.
    The examples affected are moved into the "Old" folder with the package patch files applied to 1.9.0 version of the STM32-duino.
2025-09-12 Update
    Updated OLIMEXINO-STM32 Arduino IDE instructions

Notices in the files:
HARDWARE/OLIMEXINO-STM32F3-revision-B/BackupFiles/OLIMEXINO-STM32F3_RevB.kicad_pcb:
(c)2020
